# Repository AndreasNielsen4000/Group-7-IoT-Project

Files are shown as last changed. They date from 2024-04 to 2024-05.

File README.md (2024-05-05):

# Group 7 IoT Project: Wireless Stereo Speaker System
This one of the two github pages for Group 7s project for DTU course 34346 Networking technologies and application development for the Internet of Things (IoT).
## Group Members
- Andreas Nielsen: s203833
- Alexander Nordentoft: s176361
- Rasmus Kurdahl-Martinsen: s194337
- Sergio Piqueras Moreno: s232104
- Hugo Velasco Bombin: s233845
- Anton Per Rønnedal: s203821

## Project Description

The project is a wireless speaker system that can play music from a Bluetooth or WiFi source. The system consists of four main parts with subcomponents:

1. A speaker with an ESP32-WROOM-32 microcontroller.
   1. Two custom PCBs
      1. A power board with USB-C PD and a battery management system.
      2. An audio board with a class D amplifier, a DAC, ESP32-WROOM-32, and an nRF24L01 module.
      3. Rotary encoder for volume control and switching modes.
      4. OLED display for showing the current mode, metadata, battery level and volume.
2. ESP32 IoT Bridge
   1. An ESP32-WROOM-32 microcontroller.
   2. nRF24L01 module.
3. Azure Backend
    1. WebAPI for managing the speaker system.
    2. Simple front end for controlling the speaker system.
4. Thunkable App
    1. An app for controlling the speaker system using the Azure backend.

## Description of the Speaker System

*Code in BT_I2S_URL_OLED*

The speaker system consists of a speaker with an ESP32-WROOM-32 microcontroller. The speaker is powered by a custom power board with USB-C PD and a battery management system. The speaker can be powered by three 18650 batteries or by USB-C PD. The battery can be charged using USB-C PD.

The audio is played by a custom audio board with a class D amplifier.

The speaker can play music from a Bluetooth or WiFi source. The speaker can be controlled using the Thunkable app, the Azure backend or by using the rotary encoder and OLED display on the speaker.

When powering on the speaker, a byte will be read form the EEPROM to determine the mode of the speaker. The speaker can be in one of the following modes besides being powered off:
WiFi, Bluetooth, Standby or Charge

When powered on, a short press on the rotary encoder will switch betweent the current active mode to the valid passive mode, e.g. if the speaker is in WiFi mode and charging, a short press will switch to Charge mode. A short press again will switch back to WiFi mode. If the device is not charging, the speaker will go into Standby mode instead. From Standby mode, a long press (10 seconds) will turn off the speaker.

In all modes except powered off, the speaker will show the battery level on the OLED display as well as the current mode. It will have an active nRF network to the IoT Bridge and will be able to receive and transmit payloads from the nRF network.

Once a second the speaker checks for any changes in local device parameters and if they are different from the last time the speaker will send a payload to the IoT Bridge with the new parameters. Should the speaker receive a payload from the IoT Bridge, it will parse the payload and act accordingly.

When in WiFi mode, the speaker will start by playing Radio BOB! bby default. The speaker will show the current song and Internet Radio station on the OLED display.

When in Bluetooth mode, the speaker will connect to the last connected Bluetooth device and that device will be able to play music on the speaker. The speaker will show the current song on the OLED display. When connected to a compatible device, the speaker will show the current song on the OLED display and turning the volume down to 0 sends a pause command to the device. Turning the volume up will send a play command to the device.

When in Standby mode, the speaker will not play music, but the ESP32 will still be running with the OLED display and the nRF network active.

When in Charge mode, the speaker will charge the battery and show the battery level on the OLED display.

## Description of the IoT Bridge

*Code in NRF_COM_HUB*

The IoT Bridge consists of an ESP32-WROOM-32 microcontroller and an nRF24L01 module. The IoT Bridge is connected to the Azure backend using WiFi. The IoT Bridge sends a request to the Azure backend 5 second to check for any changes in the data. If the data has changed, the IoT Bridge sends the new data to the speaker system. The IoT Bridge receives data from the speaker system and sends it to the Azure backend.

## Description of the Azure Backend

*Code in https://github.com/AndreasNielsen4000/azureradioapi]https://github.com/AndreasNielsen4000/azureradioapi*

The Azure backend consists of a WebAPI for managing the speaker system. The WebAPI is connected to the IoT Bridge using WiFi. The WebAPI receives data from the IoT Bridge and sends data to the IoT Bridge. The WebAPI has a simple front end for controlling the speaker system.

## Description of the Thunkable App

*The block-code for the app can be found here https://x.thunkable.com/projectPage/65fbfc2f66a304c1d58aabaa*

Using Thunkable an app was created for controlling the speaker system using the Azure backend. The app can be used to change the mode of the speaker system, search for new Internet Radio stations, change Internet Radio station and change the volume.
The app works by using HTTP GET to search and filter Internet Radio URLs and then HTTP POST to the Azure with updated device parameters.

AppWelcomeScreen
AppSearchScreen

## Overview of Communication

ComFlow

## Video Preview of Functionality
In the following video, the device is powered on from the off-state, going into Bluetooth mode. The rotary encoder is turned up, issuing a play request to the connected iPhone. 
Then the device is switched over to WiFi mode and playing Radio BOB!.

https://github.com/AndreasNielsen4000/Group-7-IoT-Project/assets/8758884/1d90d405-0698-4473-90d2-c6516d68bdfd

## Work Distribution

| Responsibility | Main | Secondary |
|---|---|---|
| **Mobile App** | Andreas | Alexander |
| **OLED** | Alexander | ------ |
| **LEDs** | Sergio | ------ |
| **PCBs** | Anton | ------ |
| **Soldering** | Anton | ------ |
| **3D Design** | Sergio | Hugo |
| **Azure** | Rasmus | Andreas |
| **Back-end** | Andreas | Rasmus |
| **Front-end** | Andreas | Alexander |
| **IoT bridge** | Rasmus | Andreas, Alexander |
| **nRF** | Sergio | Rasmus, Andreas |
| **nRF Network** | Andreas | Alexander, Sergio |
| **WiFi (mode)** | Alexander | Andreas |
| **Bluetooth (mode)** | Alexander | Andreas |
| **EEPROM** | Alexander | ------ |
| **Battery Reading** | Rasmus | ------ |
| **Power Delivery** | Anton | ------ |
| **BMS** | Anton | ------ |
| **Rotary encoder** | Anton & Alexander | ------ |
| **State Machine** | Anton | ------ |
| **Code Integration** | Andreas & Alexander | Anton |
| **Final prototype assembly**  | Alexander, Anton & Sergio | ------ |
| **Report** | All | ------ |
| **Poster** | All | ------ |

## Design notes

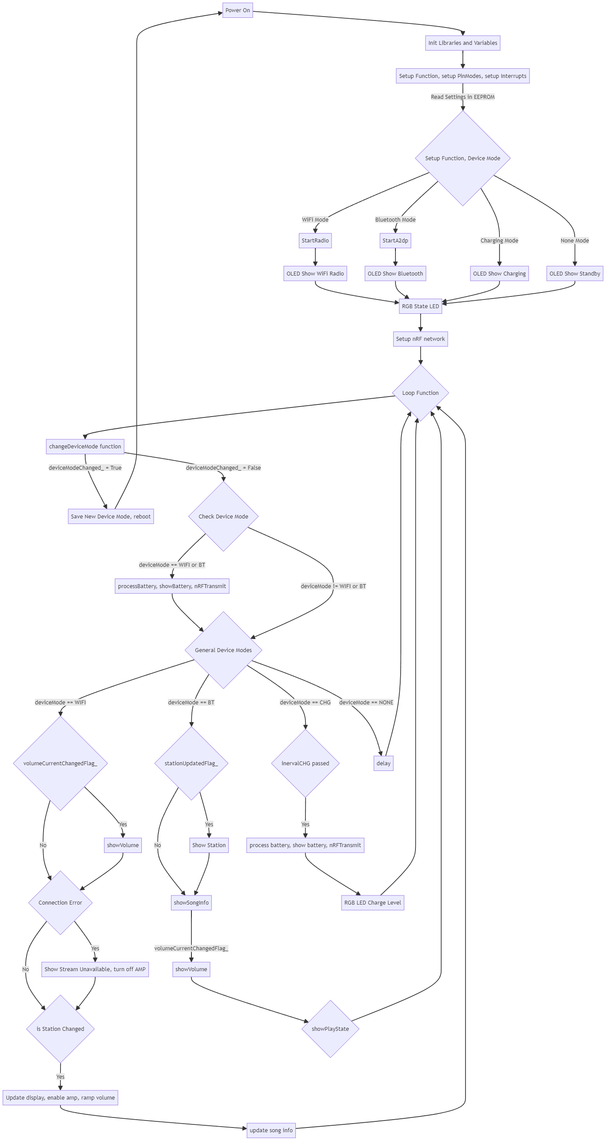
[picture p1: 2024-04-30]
speaker_code_overview.png

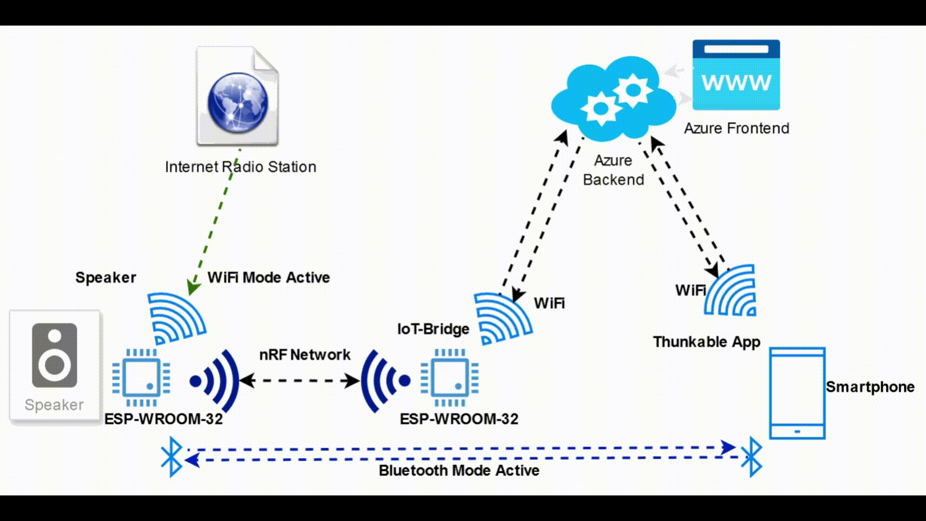
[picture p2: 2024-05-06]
ComFlow.gif

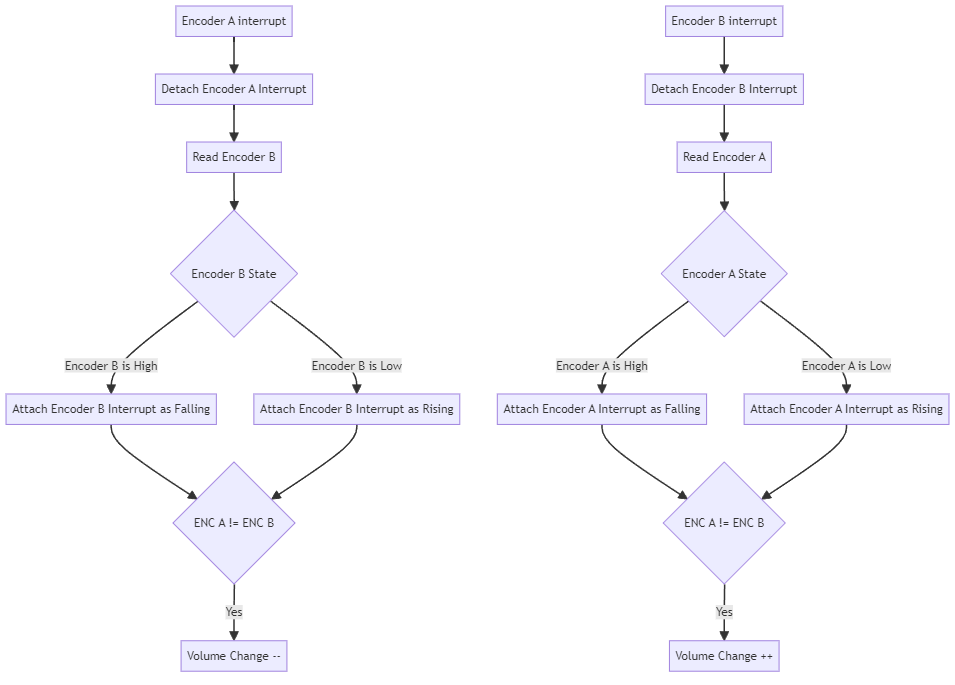
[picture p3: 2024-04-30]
Encoder flowchart.png

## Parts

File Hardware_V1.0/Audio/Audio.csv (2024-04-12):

Reference | Value | Footprint | Qty | MPN | Description
C29,C30 | 12p | Capacitor_SMD:C_0603_1608Metric_Pad1.08x0.95mm_HandSolder | 2 | CL10C120JB8NNNC | MLCC 50V 5% C0G
C28 | 100p | Capacitor_SMD:C_0603_1608Metric_Pad1.08x0.95mm_HandSolder | 1 | CL10C101JB8NNND | MLCC 50V 5% C0G
C14,C16,C27,C64,C65,C76 | 2.2n | Capacitor_SMD:C_0603_1608Metric_Pad1.08x0.95mm_HandSolder | 6 | CL10B222KB8NNND | MLCC 50V 10% X7R
C13 | 33n | Capacitor_SMD:C_0603_1608Metric_Pad1.08x0.95mm_HandSolder | 1 | CL10B333KB8NNNC | MLCC 50V 10% X7R
C1,C2,C4,C5,C6,C8,C9,C12,C15,C17,C21,C22,C49,C61,C62,C68,C69,C70,C71,C72,C73,C74,C75 | 100n | Capacitor_SMD:C_0603_1608Metric_Pad1.08x0.95mm_HandSolder | 23 | CL10B104JB8NNNC | MLCC 50V 5% X7R
C45,C46,C47,C48 | 220n | Capacitor_SMD:C_0603_1608Metric_Pad1.08x0.95mm_HandSolder | 4 | CL10B224KB8NNNC | MLCC 50V 5% X7R
C52,C53,C54,C55 | 470n | Capacitor_SMD:C_0805_2012Metric_Pad1.18x1.45mm_HandSolder | 4 | CL21B474KBFNNNE | MLCC 50V 10% X7R
C18,C19,C20,C23,C25,C26,C31 | 1u | Capacitor_SMD:C_0603_1608Metric_Pad1.08x0.95mm_HandSolder | 7 | CL10A105KB8NNNC | MLCC 50V 10% X5R
C10,C11 | 2.2u | Capacitor_SMD:C_0603_1608Metric_Pad1.08x0.95mm_HandSolder | 2 | CL10A225KP8NNNC | MLCC 10V 10% X5R
C7 | 4.7u | Capacitor_SMD:C_0603_1608Metric_Pad1.08x0.95mm_HandSolder | 1 | GRM188R6YA475KE15J | MLCC 35V 10% X5R
L1,L2,L3,L4,L5 | 10uH | 0_Costum:1274AS | 5 | DD1274AS-H-100M=P3 | Power inductor SMD 4.4A 20%
C3,C24,C32,C33,C34,C35,C36,C37,C38,C39,C40,C41,C42,C43,C44,C50,C51,C56,C57,C58,C59,C60,C63,C66,C67 | 10u | Capacitor_SMD:C_1206_3216Metric_Pad1.33x1.80mm_HandSolder | 25 | CL31B106KBHNNNE | MLCC 50V 10% X7R
Y1 | 16 MHz | Crystal:Crystal_SMD_2520-4Pin_2.5x2.0mm | 1 | ECS-160-10-36-CKM-TR3
R24,R25 | 470R | Resistor_SMD:R_0603_1608Metric_Pad0.98x0.95mm_HandSolder | 2 | CRCW0603470RFKEA | Thick Film Resistor 1/10watt 1%
R10,R21,R22,R26,R27,R31,R32 | 2k | Resistor_SMD:R_0603_1608Metric_Pad0.98x0.95mm_HandSolder | 7 | CRCW06032K00FKEC | Thick Film Resistor 1/10watt 1%
R4,R5 | 5.1k | Resistor_SMD:R_0603_1608Metric_Pad0.98x0.95mm_HandSolder | 2 | CRCW06035K10FKEA | Thick Film Resistor 1/10watt 1%
R34 | 5.6k | Resistor_SMD:R_0603_1608Metric_Pad0.98x0.95mm_HandSolder | 1 | CRCW06035K60FKEA | Thick Film Resistor 1/10watt 1%
R15,R16,R17,R19,R20 | 10k | Resistor_SMD:R_0603_1608Metric_Pad0.98x0.95mm_HandSolder | 5 | CRCW060310K0FKEC | Thick Film Resistor 1/10watt 1%
R8,R23,R29,R37 | 22k | Resistor_SMD:R_0603_1608Metric_Pad0.98x0.95mm_HandSolder | 4 | CRCW060322K0FKEA | Thick Film Resistor 1/10watt 1%
R9 | 47.5k | Resistor_SMD:R_0603_1608Metric_Pad0.98x0.95mm_HandSolder | 1 | CRCW060347K5FKEA | Thick Film Resistor 1/10watt 1%
R36 | 51k | Resistor_SMD:R_0603_1608Metric_Pad0.98x0.95mm_HandSolder | 1 | CRCW060351K0FKEA | Thick Film Resistor 1/10watt 1%
R3,R12,R13,R14,R35 | 100k | Resistor_SMD:R_0603_1608Metric_Pad0.98x0.95mm_HandSolder | 5 | CRCW0603100KFKEA | Thick Film Resistor 1/10watt 1%
R7 | 200k | Resistor_SMD:R_0603_1608Metric_Pad0.98x0.95mm_HandSolder | 1 | CRCW0603200KFKEA | Thick Film Resistor 1/10watt 1%
R1,R2,R6,R11,R30,R38 | 1M | Resistor_SMD:R_0603_1608Metric_Pad0.98x0.95mm_HandSolder | 6 | CRCW06031M00FKEC | Thick Film Resistor 1/10watt 1%
R28,R33,R39,R40 | (NC) | Resistor_SMD:R_0603_1608Metric_Pad0.98x0.95mm_HandSolder | 4
D10,D11,D12 | 1N4148W | Diode_SMD:D_SOD-123 | 3
U5 | 2450BM14E0002T | Snapeda:2450BM14E0003T_JOT-L | 1 | 2450BM14A0002T
Q1,Q2 | BC817 | Package_TO_SOT_SMD:SOT-23 | 2 | BC817-QR | NPN transistor, base/emitter/collector
SW2 | BOOT | Button_Switch_SMD:Panasonic_EVQPUK_EVQPUB | 1 | EVQ-PUK02K | Tactile Switch
J2,J3,J4,J5 | Conn_01x04 | Connector_PinSocket_2.54mm:PinSocket_1x04_P2.54mm_Vertical | 4 |  | Generic connector, single row, 01x04, script generated (kicad-library-utils/schlib/autogen/connector/)
U2 | CP2102N-Axx-xQFN28 | Package_DFN_QFN:QFN-28-1EP_5x5mm_P0.5mm_EP3.35x3.35mm | 1 | CP2102N-A02-GQFN28 | USB to UART master bridge, QFN-28
SW3 | EN | Button_Switch_SMD:Panasonic_EVQPUK_EVQPUB | 1 | EVQ-PUK02K | Tactile Switch
U1 | ESP32-WROOM-32E | RF_Module:ESP32-WROOM-32D | 1 | ESP32-WROOM-32E-N16 | RF Module, ESP32-D0WD-V3 SoC, without PSRAM, Wi-Fi 802.11b/g/n, Bluetooth, BLE, 32-bit, 2.7-3.6V, onboard antenna, SMD
H1,H2,H3,H4 | Hole | MountingHole:MountingHole_3.2mm_M3_DIN965_Pad | 4 |  | Mounting Hole with connection
JP1 | Jumper | Jumper:SolderJumper-3_P1.3mm_Bridged12_RoundedPad1.0x1.5mm | 1 |  | 3-pole Solder Jumper, pins 1+2 closed/bridged
D9 | LED_amber | LED_SMD:LED_0603_1608Metric_Pad1.05x0.95mm_HandSolder | 1 | 150060YS75000
D8,D13 | LED_green | LED_SMD:LED_0603_1608Metric_Pad1.05x0.95mm_HandSolder | 2 | 150060GS75000
D14 | LED_red | LED_SMD:LED_0603_1608Metric_Pad1.05x0.95mm_HandSolder | 1 | 150060RS75000
U7 | LMR51430 | Package_TO_SOT_SMD:SOT-23-6 | 1 | LMR51430YDDCR | 4.5-V to 36-V, 3-A synchronous buck converter with 40-µA IQ, SOT-23-6
AE1 | MIFA | RF_Antenna:Texas_SWRA117D_2.4GHz_Right | 1 |  | Antenna with extra pin for shielding
U4 | nRF24L01P | Package_DFN_QFN:QFN-20-1EP_4x4mm_P0.5mm_EP2.5x2.5mm | 1 | nRF24L01P | nRF24L01+, Ultra low power 2.4GHz RF Transceiver, QFN20 4x4mm
U3 | PCM5101A | Package_SO:TSSOP-20_4.4x6.5mm_P0.65mm | 1 | PCM5101AQPWRQ1 | 2.1 VRMS, 106dB Audio Stereo DAC with PLL and 32-bit, 384kHz PCM Interface, TSSOP-20
D1,D2,D3,D5,D6 | PMEG60T | Diode_SMD:Nexperia_CFP3_SOD-123W | 5 | PMEG60T30ELRX
D4,D15 | PMEG3020ER | Diode_SMD:Nexperia_CFP3_SOD-123W | 2 | PMEG3020ER,115
D7 | RGB LED | 0_Costum:RGB_LED | 1
SW1 | Rotary Encoder | 0_Costum:EC11_RotaryEncoder | 1
SW4 | SW_DIP_x02 | Button_Switch_SMD:SW_DIP_SPSTx02_Slide_6.7x6.64mm_W8.61mm_P2.54mm_LowProfile | 1 | 219-2MST | 2x DIP Switch, Single Pole Single Throw (SPST) switch, small symbol
J6,J7 | Terminal | TerminalBlock:TerminalBlock_bornier-2_P5.08mm | 2 |  | Generic screw terminal, single row, 01x02, script generated (kicad-library-utils/schlib/autogen/connector/)
U6 | TPA3128 | 0_Costum:DAP32_4P36X4P11_TEX | 1 | TPA3128D2DAPR
J1 | USB_C_Receptacle | Connector_USB:USB_C_Receptacle_GCT_USB4105-xx-A_16P_TopMnt_Horizontal | 1 | USB4105-GF-A-120 | USB 2.0-only 16P Type-C Receptacle connector

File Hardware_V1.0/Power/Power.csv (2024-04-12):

Reference | Value | Footprint | Qty | MPN | Description
B3 | ~ | 0_Costum:BLM_18650x3 | 1
C1,C2,C3,C4,C5,C8,C9,C10,C16,C17,C18,C25,C27,C28,C29,C30 | 100n | Capacitor_SMD:C_0603_1608Metric_Pad1.08x0.95mm_HandSolder | 16 | CL10B104JB8NNNC | MLCC 50V 5% X7R
C6,C7,C12,C13,C14,C15,C22,C24,C26,C35 | 1u | Capacitor_SMD:C_0603_1608Metric_Pad1.08x0.95mm_HandSolder | 10 | CL10A105KB8NNNC | MLCC 50V 10% X5R
C11 | 4.7u | Capacitor_SMD:C_0603_1608Metric_Pad1.08x0.95mm_HandSolder | 1 | GRM188R6YA475KE15J | MLCC 35V 10% X5R
C19,C20,C21,C31,C33,C34 | 10u | Capacitor_SMD:C_1206_3216Metric_Pad1.33x1.80mm_HandSolder | 6 | CL31B106KBHNNNE | MLCC 50V 10% X7R
C23 | 33n | Capacitor_SMD:C_0603_1608Metric_Pad1.08x0.95mm_HandSolder | 1 | CL10B333KB8NNNC | MLCC 50V 10% X7R
C32 | 22p | Capacitor_SMD:C_0603_1608Metric_Pad1.08x0.95mm_HandSolder | 1 | CL10C220JB8NNNC | MLCC 50V 5% C0G
D1,D8 | PMEG60T | Diode_SMD:Nexperia_CFP3_SOD-123W | 2 | PMEG60T30ELRX
D2,D3,D4 | ESDA25P35 | Snapeda:QFN1610_STM-L | 3 | ESDA25P35-1U1M
D5,D7 | LED_green | LED_SMD:LED_0603_1608Metric_Pad1.05x0.95mm_HandSolder | 2 | 150060GS75000
D6 | LED_amber | LED_SMD:LED_0603_1608Metric_Pad1.05x0.95mm_HandSolder | 1 | 150060YS75000
D9,D10 | PMEG3020ER | Diode_SMD:Nexperia_CFP3_SOD-123W | 2 | PMEG3020ER,115
D11 | ESDA25W | Package_TO_SOT_SMD:SOT-323_SC-70_Handsoldering | 1 | ESDA25W | TVS Diode Array
H1,H2,H3,H4 | Hole | MountingHole:MountingHole_3.2mm_M3_DIN965_Pad | 4 |  | Mounting Hole with connection
J1,J8,J9,J10,J11 | Conn_01x04 | -- mixed values -- | 5 | -- mixed values -- | -- mixed values --
J2 | (NC) | Connector_BarrelJack:BarrelJack_Wuerth_694106106102_2.0x5.5mm | 1 | 694106106102 | DC Barrel Jack with an internal switch
J5 | Barrel_Jack_Switch | Connector_BarrelJack:BarrelJack_Wuerth_694106106102_2.0x5.5mm | 1 | 694106106102 | DC Barrel Jack with an internal switch
J6 | USB_C_Receptacle_USB2.0_16P | Connector_USB:USB_C_Receptacle_GCT_USB4105-xx-A_16P_TopMnt_Horizontal | 1 | USB4105-GF-A-120 | USB 2.0-only 16P Type-C Receptacle connector
L1 | 10uH | 0_Costum:1274AS | 1 | DD1274AS-H-100M=P3 | Power inductor SMD 4.4A 20%
Q1,Q3,Q9,Q10 | SiRA88DP | Package_SO:PowerPAK_SO-8_Single | 4 | SIRA88DP-T1-GE3
Q2,Q4 | Si2369DS | Package_TO_SOT_SMD:SOT-23 | 2 | SI2369DS-T1-GE3
Q6,Q7,Q8,Q11 | SiS413DN | Package_SO:Vishay_PowerPAK_1212-8_Single | 4 | SIS413DN-T1-GE3
R1,R22,R23,R40 | 5.1k | Resistor_SMD:R_0603_1608Metric_Pad0.98x0.95mm_HandSolder | 4 | CRCW06035K10FKEA | Thick Film Resistor 1/10watt 1%
R2,R3,R4,R5,R8,R10,R30,R44 | 100R | Resistor_SMD:R_0603_1608Metric_Pad0.98x0.95mm_HandSolder | 8 | CRCW0603100RFKEC | Thick Film Resistor 1/10watt 1%
R6,R20,R25,R37,R48 | 1k | Resistor_SMD:R_0603_1608Metric_Pad0.98x0.95mm_HandSolder | 5 | CRCW06031K00FKEC | Thick Film Resistor 1/10watt 1%
R7,R12,R13,R15,R21,R35,R42 | 10k | Resistor_SMD:R_0603_1608Metric_Pad0.98x0.95mm_HandSolder | 7 | CRCW060310K0FKEC | Thick Film Resistor 1/10watt 1%
R11,R17,R18,R49 | 1M | Resistor_SMD:R_0603_1608Metric_Pad0.98x0.95mm_HandSolder | 4 | CRCW06031M00FKEC | Thick Film Resistor 1/10watt 1%
R14 | 750k | Resistor_SMD:R_0603_1608Metric_Pad0.98x0.95mm_HandSolder | 1 | CRCW0603750KFKEA | Thick Film Resistor 1/10watt 1%
R16,R46 | 430k | Resistor_SMD:R_0603_1608Metric_Pad0.98x0.95mm_HandSolder | 2 | CRCW0603430KFKEA | Thick Film Resistor 1/10watt 1%
R19 | 8m | 0_Costum:SenseResistor_1206 | 1 | MSMA1206R0080FCM | Current sense resistor 1W 1% 50 PPM/C
R24 | 470R | Resistor_SMD:R_0603_1608Metric_Pad0.98x0.95mm_HandSolder | 1 | CRCW0603470RFKEC | Thick Film Resistor 1/10watt 1%
R28,R34,R36,R39,R41 | 100k | Resistor_SMD:R_0603_1608Metric_Pad0.98x0.95mm_HandSolder | 5 | CRCW0603100KFKEA | Thick Film Resistor 1/10watt 1%
R29 | 22k | Resistor_SMD:R_0603_1608Metric_Pad0.98x0.95mm_HandSolder | 1 | CRCW060322K0FKEA | Thick Film Resistor 1/10watt 1%
R38 | 10R | Resistor_SMD:R_0603_1608Metric_Pad0.98x0.95mm_HandSolder | 1 | CRCW060310R0FKEC | Thick Film Resistor 1/10watt 1%
R43,R47 | 10m | 0_Costum:SenseResistor_1206 | 2 | MFSA1206R0100FCM | Current sense resistor 1W 1% 50 PPM/C
R45 | 9.1k | Resistor_SMD:R_0603_1608Metric_Pad0.98x0.95mm_HandSolder | 1 | CRCW06039K10FKEA | Thick Film Resistor 1/10watt 1%
R50 | 200k | Resistor_SMD:R_0603_1608Metric_Pad0.98x0.95mm_HandSolder | 1 | CRCW0603200KFKEA | Thick Film Resistor 1/10watt 1%
TH1,TH3 | NCP18XH103 | Resistor_SMD:R_0603_1608Metric_Pad0.98x0.95mm_HandSolder | 2 | NCP18XH103F03RB
U1 | TAS:BQ7791500 | Package_SO:TSSOP-24_4.4x7.8mm_P0.65mm | 1 | BQ7791500PWR
U2 | STUSB4500 | Package_DFN_QFN:QFN-24-1EP_4x4mm_P0.5mm_EP2.7x2.7mm | 1 | STUSB4500QTR
U3 | BQ24617 | Package_DFN_QFN:QFN-24-1EP_4x4mm_P0.5mm_EP2.15x2.15mm_ThermalVias | 1 | BQ24617RGER

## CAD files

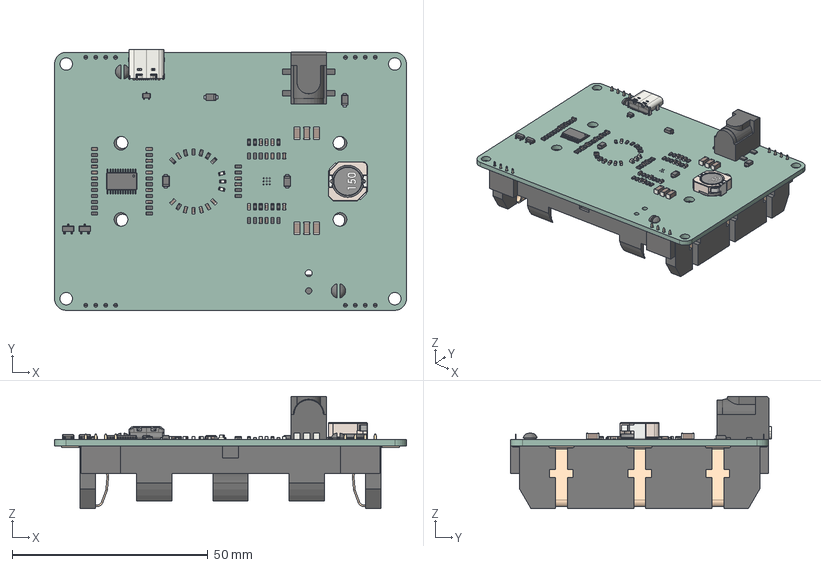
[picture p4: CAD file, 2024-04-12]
Hardware_V1.0/Power/Power.step
90.0 x 66.7 x 28.7 mm
R_0603_1608Metric x 43
C_1206_3216Metric x 6
C_0603_1608Metric x 29
CQ assembly x 4
USB_C_Receptacle_16P_TopMnt_Horizontal_GCT_USB4105-xx-A
WURTH_7447713150
LED_0603_1608Metric x 3
SOT_323_SC_70
SOT_23 x 2
TSSOP_24_44x78mm_P065mm
BarrelJackSMD v3
Hold_18650-3p_smd
PinSocket_1x04_P254mm_Vertical x 4
_autosave-Power_PCB

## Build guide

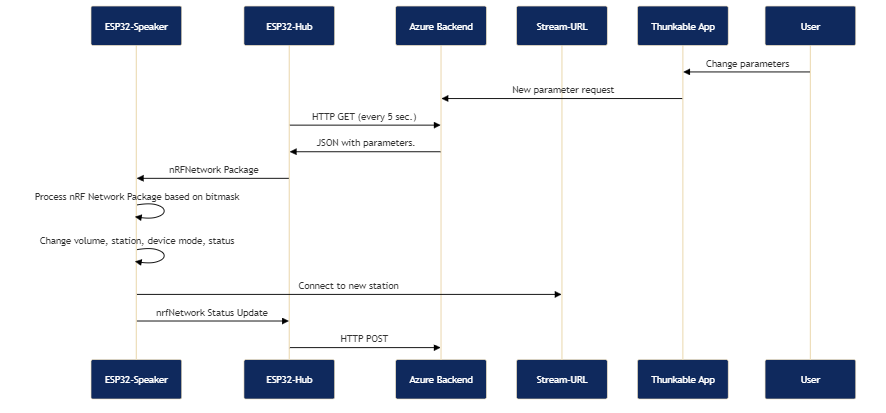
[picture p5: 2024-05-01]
User operation flow chart.png

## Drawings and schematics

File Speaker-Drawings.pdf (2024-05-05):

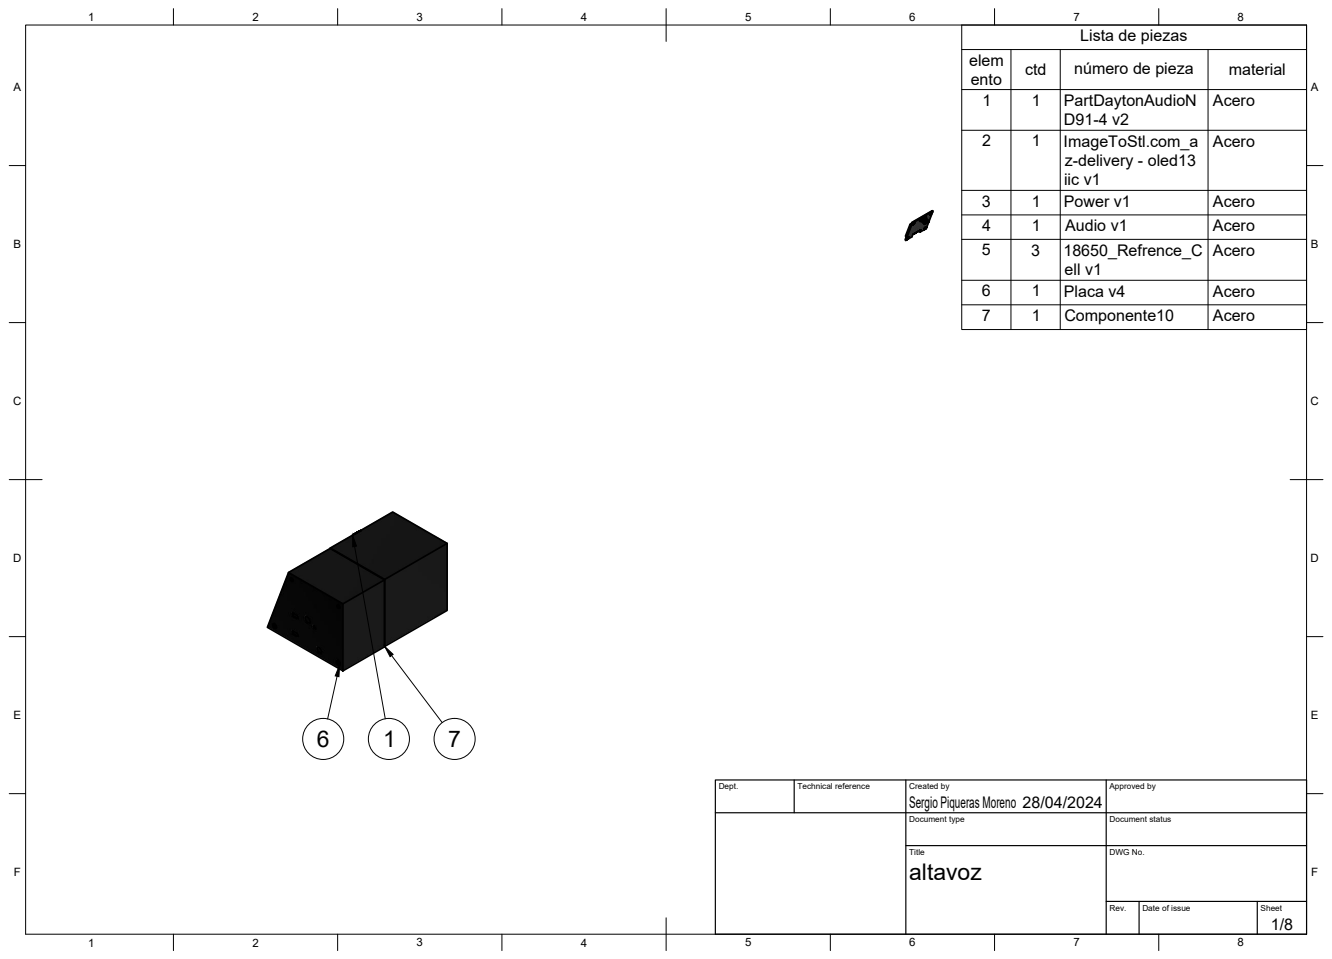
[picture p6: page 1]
Title; DWG No.; Rev.; Date of issue; Sheet

Lista de piezas

elem ento | ctd | número de pieza | material

1 | 1 | PartDaytonAudioN D91-4 v2 | Acero

2 | 1 | ImageToStl.com_a z-delivery - oled13 iic v1 | Acero

3 | 1 | Power v1 | Acero
4 | 1 | Audio v1 | Acero
5 | 3 | 18650_Refrence_C ell v1 | Acero

6 | 1 | Placa v4 | Acero
7 | 1 | Componente10 | Acero

Dept. | Technical reference | Created by Sergio Piqueras Moreno 28/04/2024 | Approved by

Document type | Document status

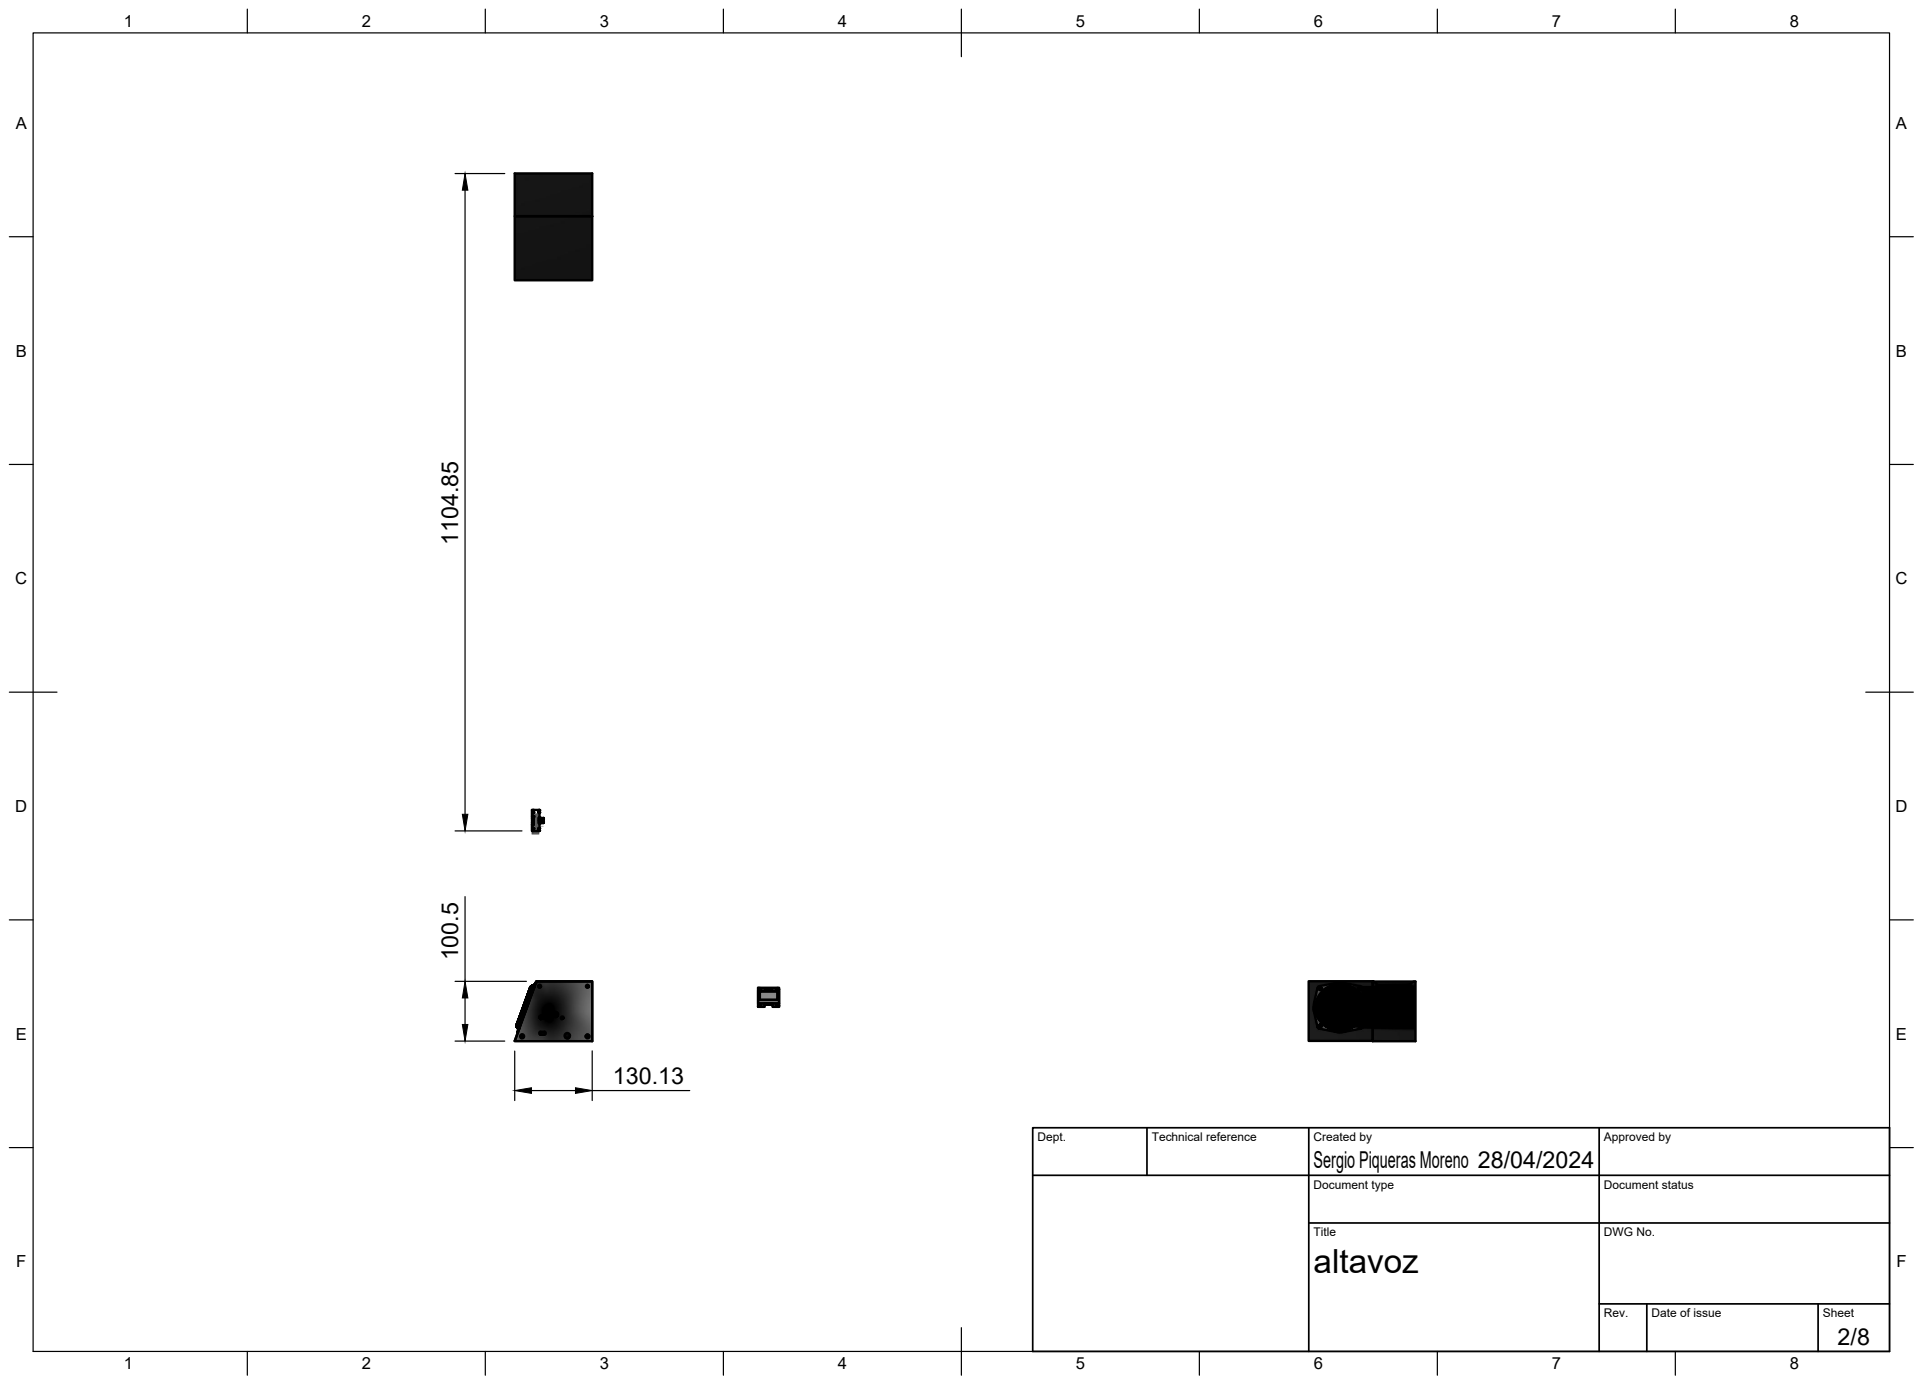
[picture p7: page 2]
Dept.; Technical reference; Created by; Approved by; Document type; Document status; Title; DWG No.

Sergio Piqueras Moreno

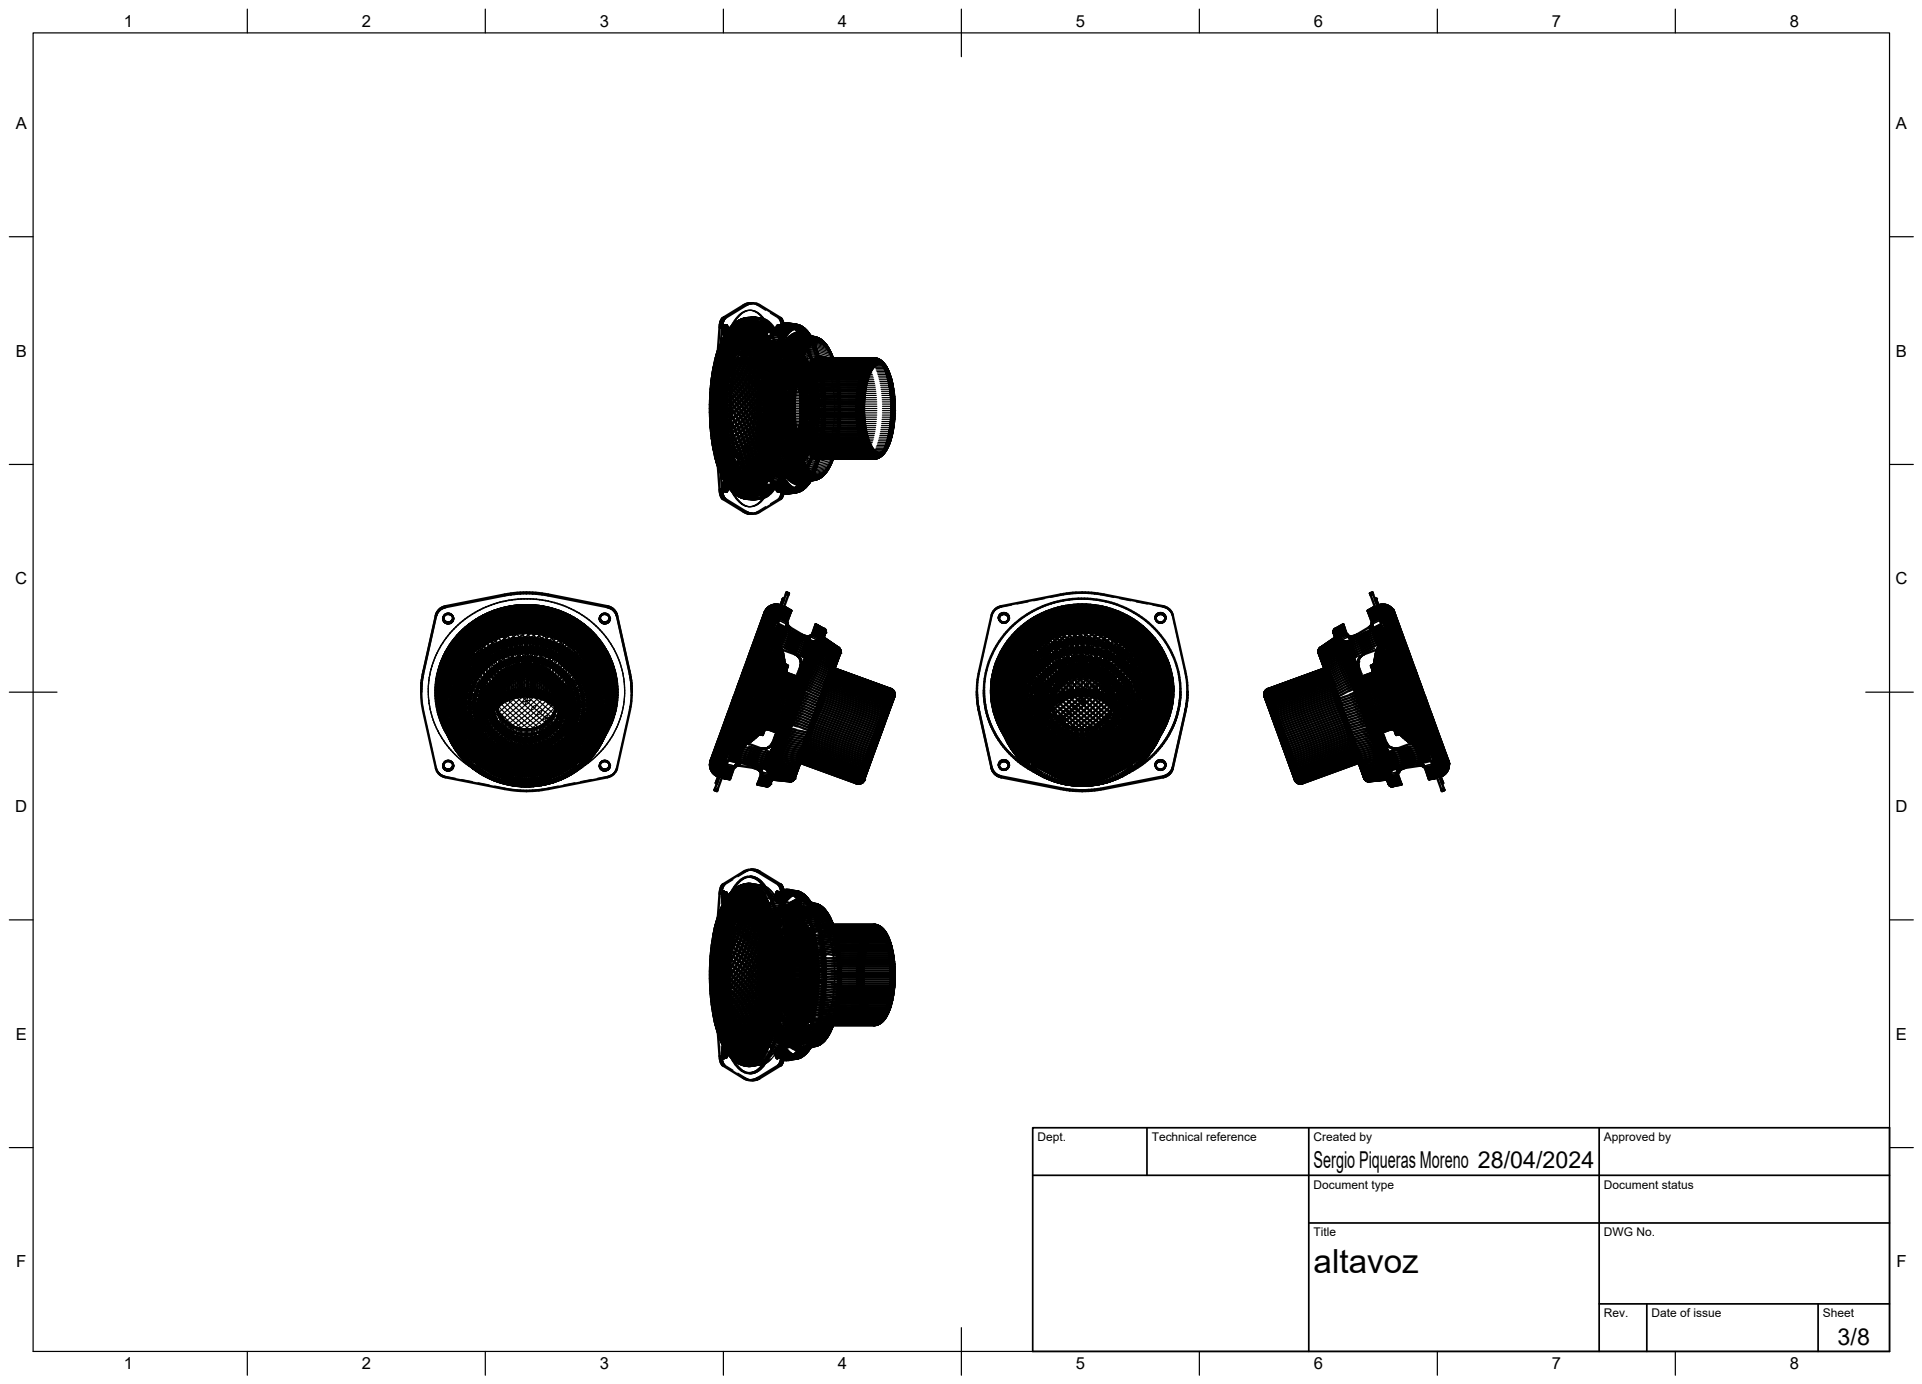
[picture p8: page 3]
Dept.; Technical reference; Created by; Approved by; Document type; Document status; Title; DWG No.

Sergio Piqueras Moreno

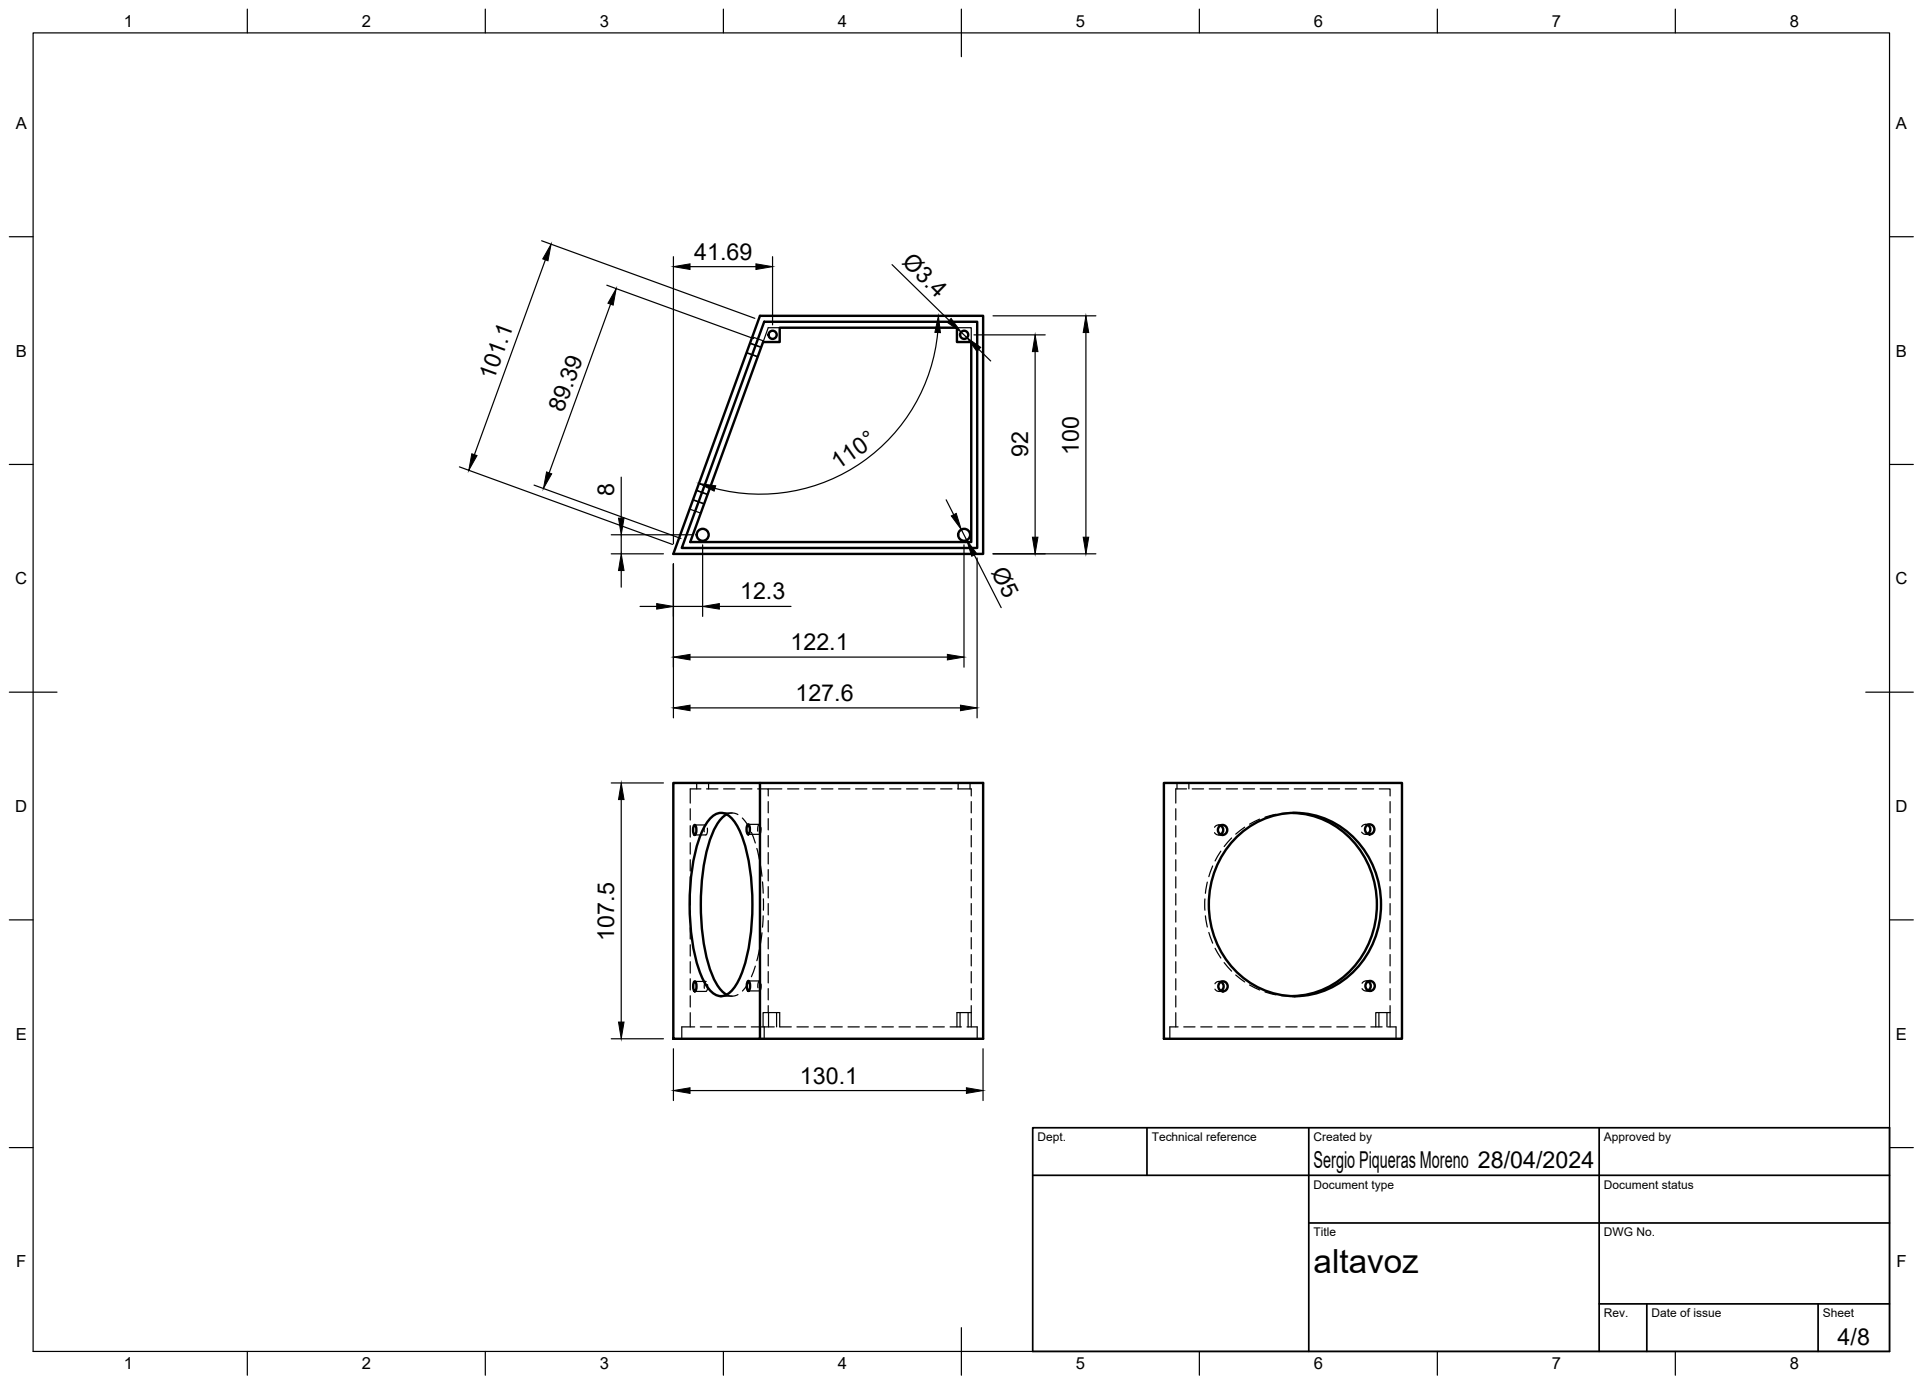
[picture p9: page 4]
Title; DWG No.

Sergio Piqueras Moreno 107.5

Dept. | Technical reference | Created by 28/04/2024 | Approved by

Document type | Document status

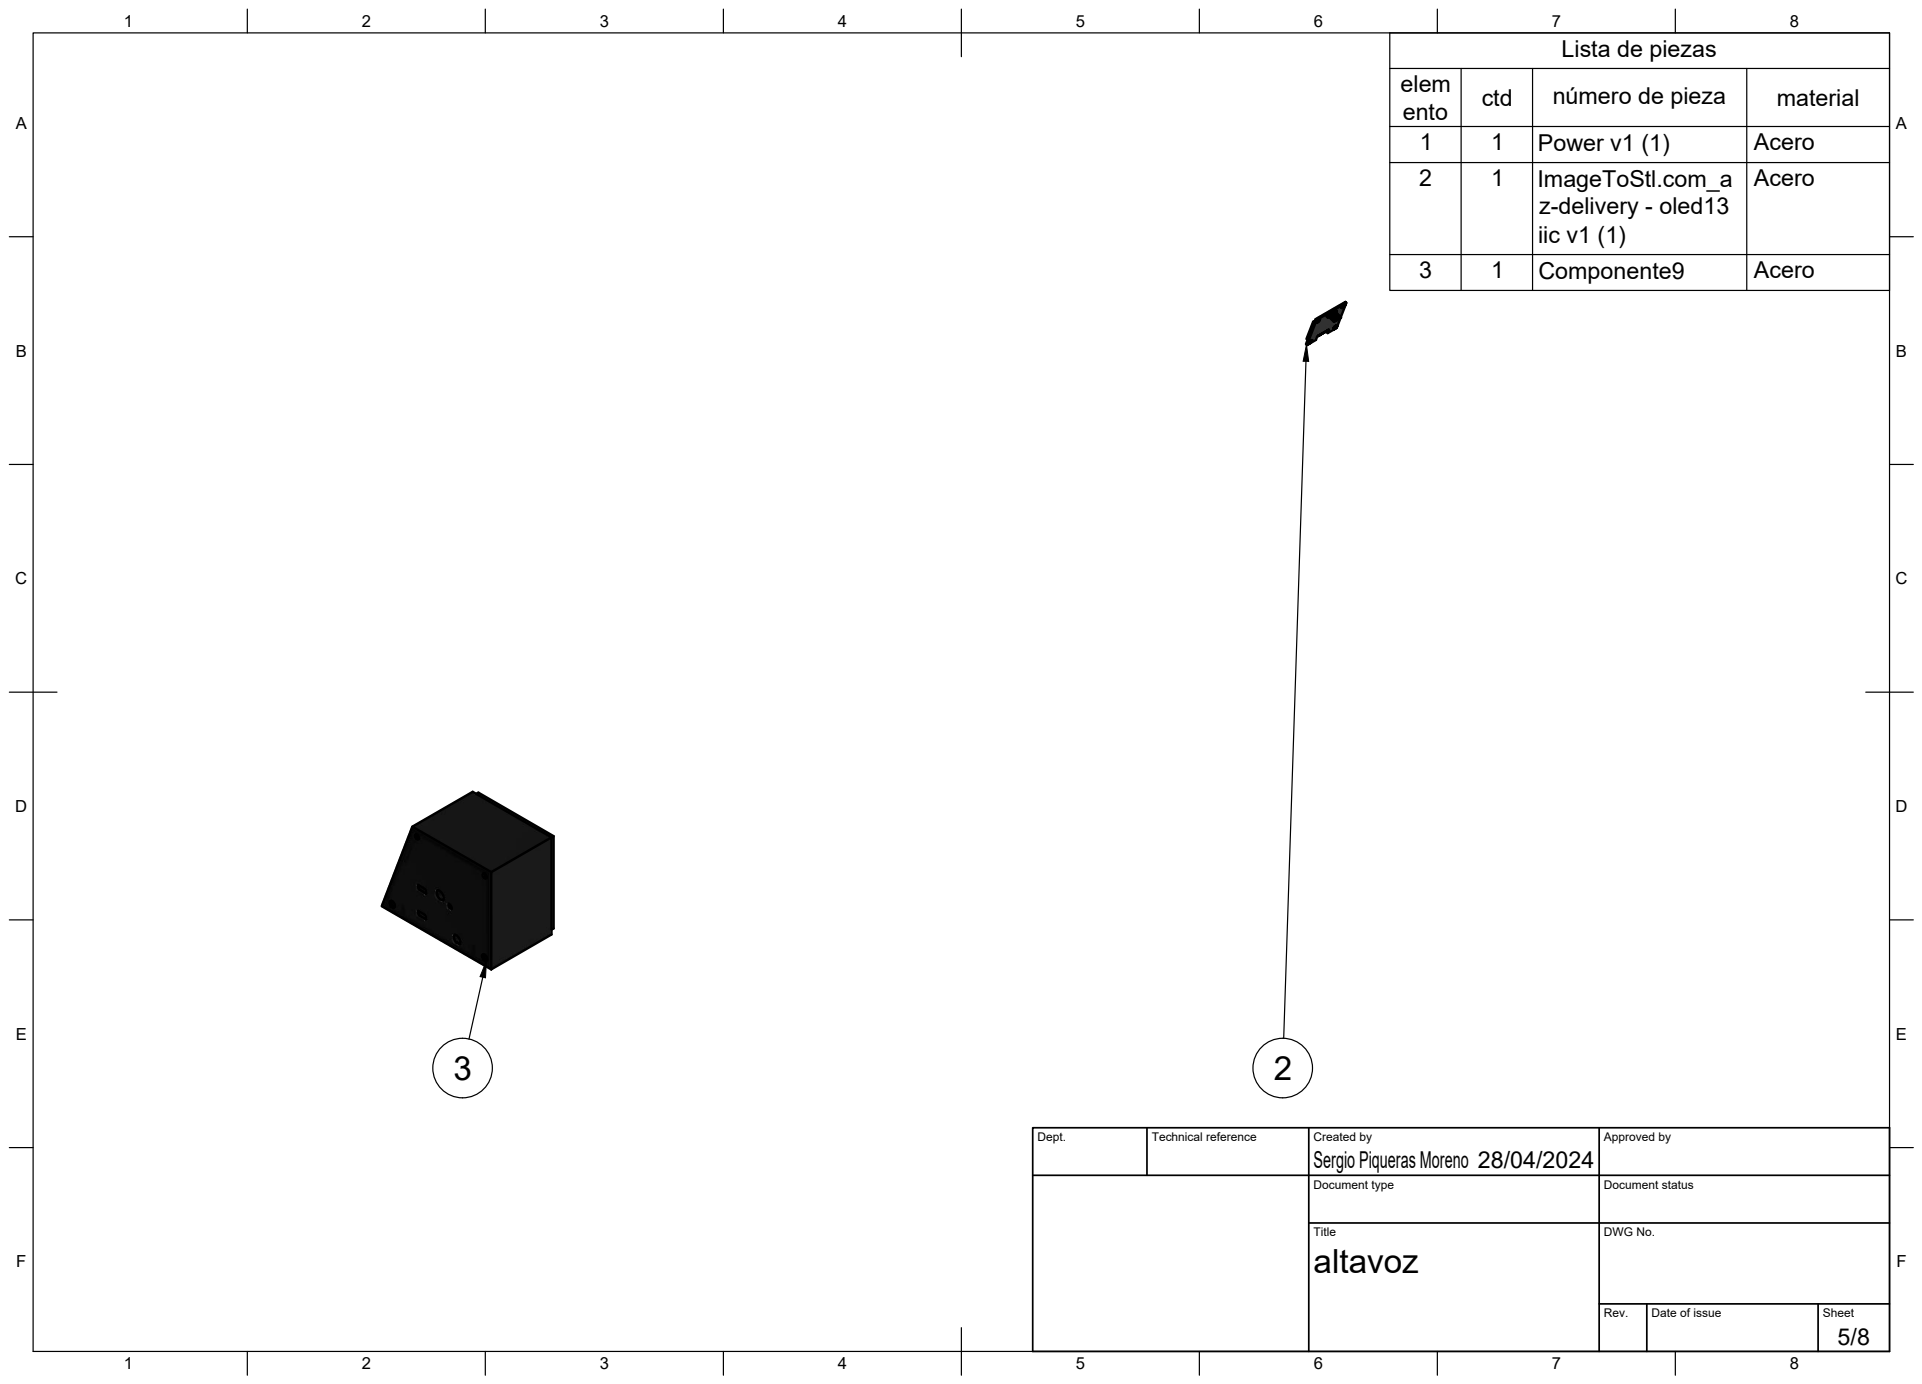
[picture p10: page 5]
Title; DWG No.

Lista de piezas

elem ento | ctd | número de pieza | material

1 | 1 | Power v1 (1) | Acero
2 | 1 | ImageToStl.com_a z-delivery - oled13 iic v1 (1) | Acero

3 | 1 | Componente9 | Acero

Dept. | Technical reference | Created by Sergio Piqueras Moreno 28/04/2024 | Approved by

Document type | Document status

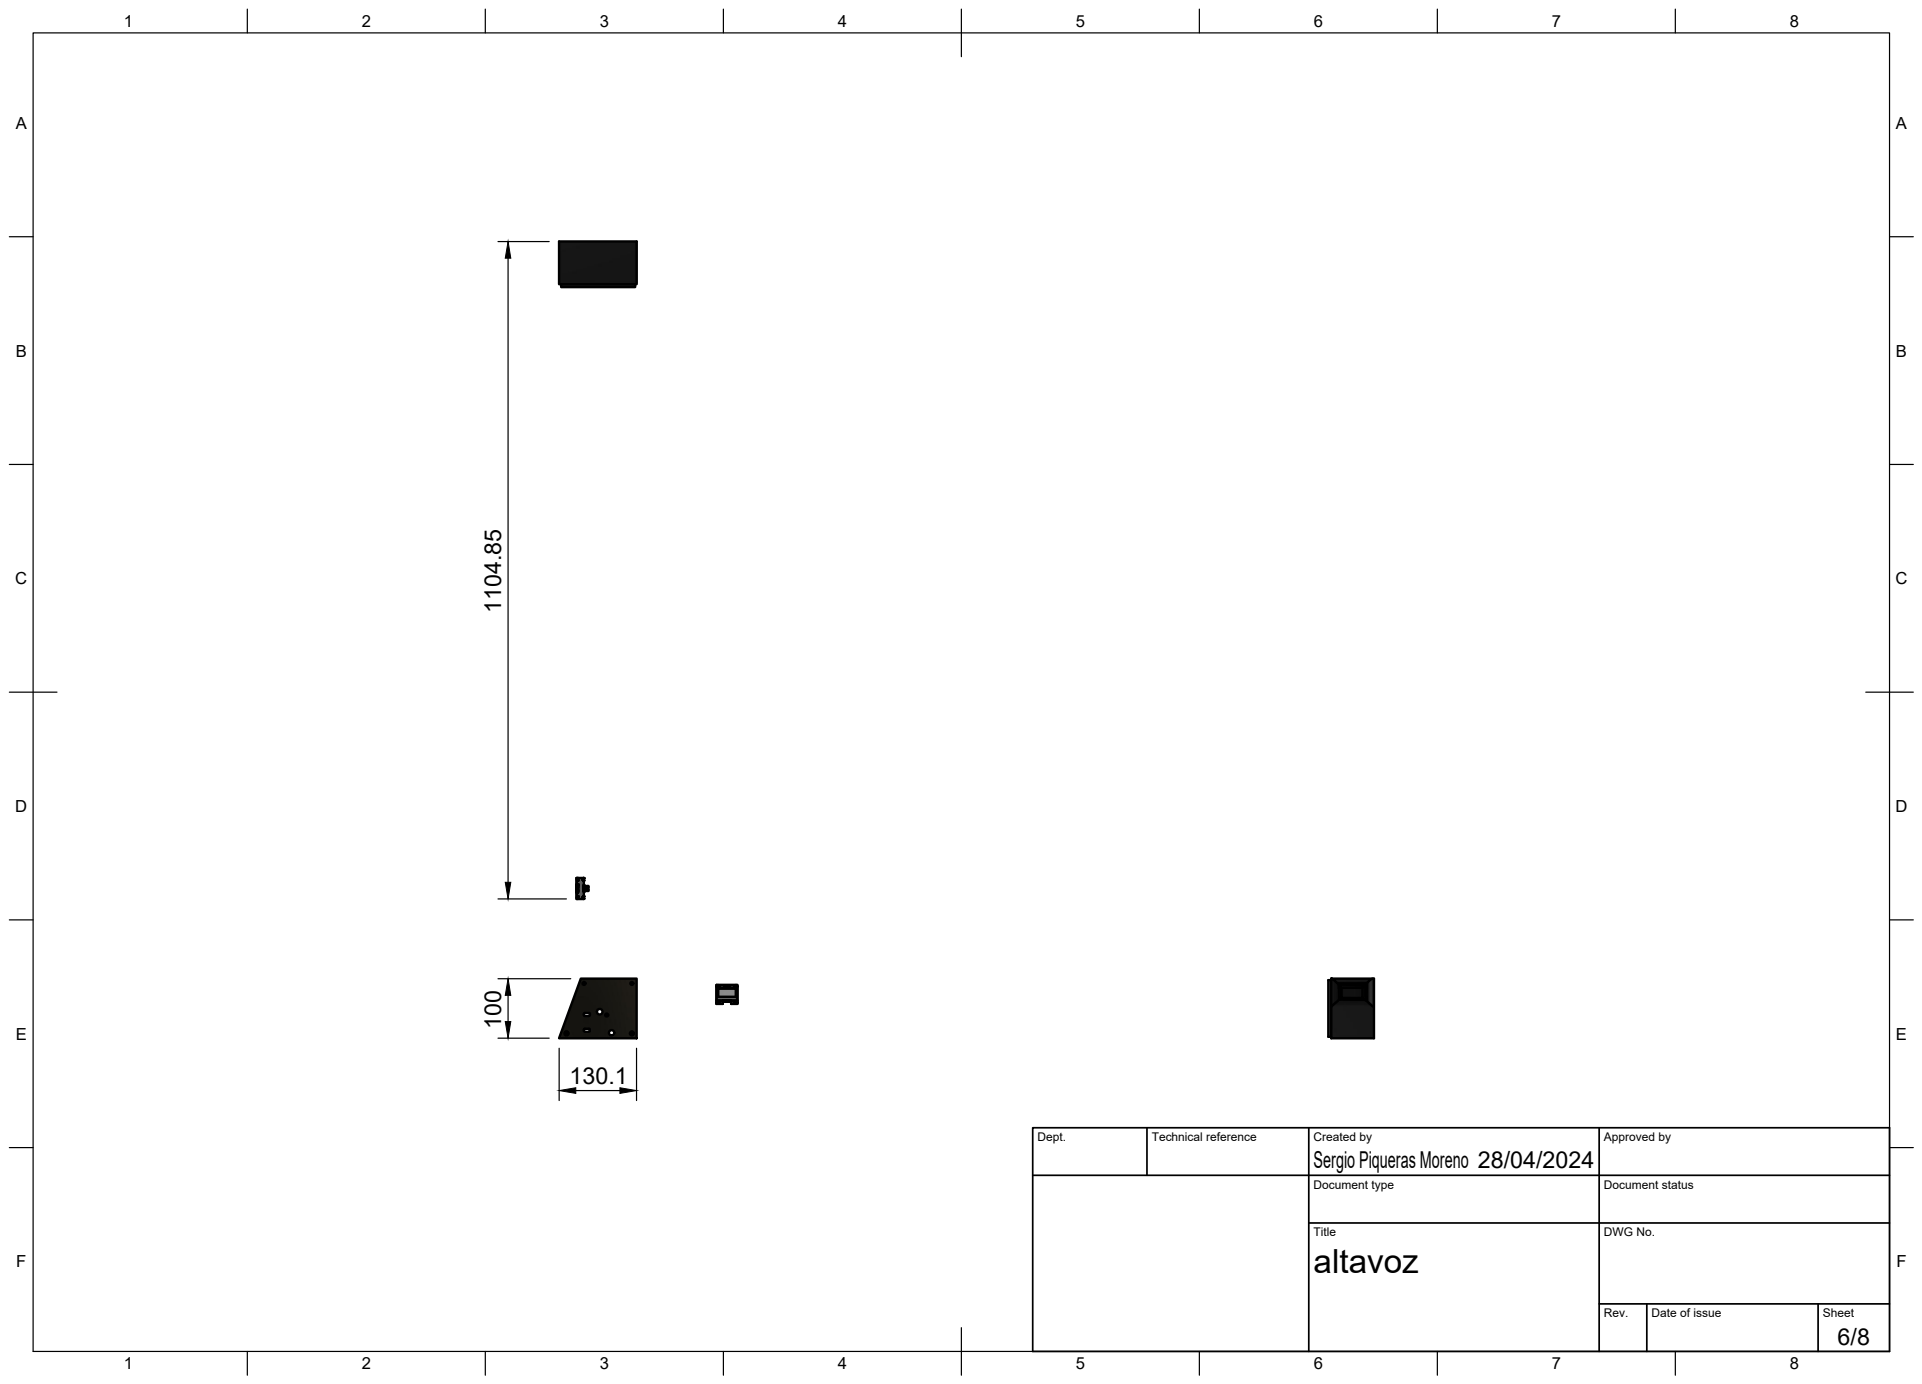
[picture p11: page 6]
Title; DWG No.

Dept. | Technical reference | Created by Sergio Piqueras Moreno 28/04/2024 | Approved by

Document type | Document status

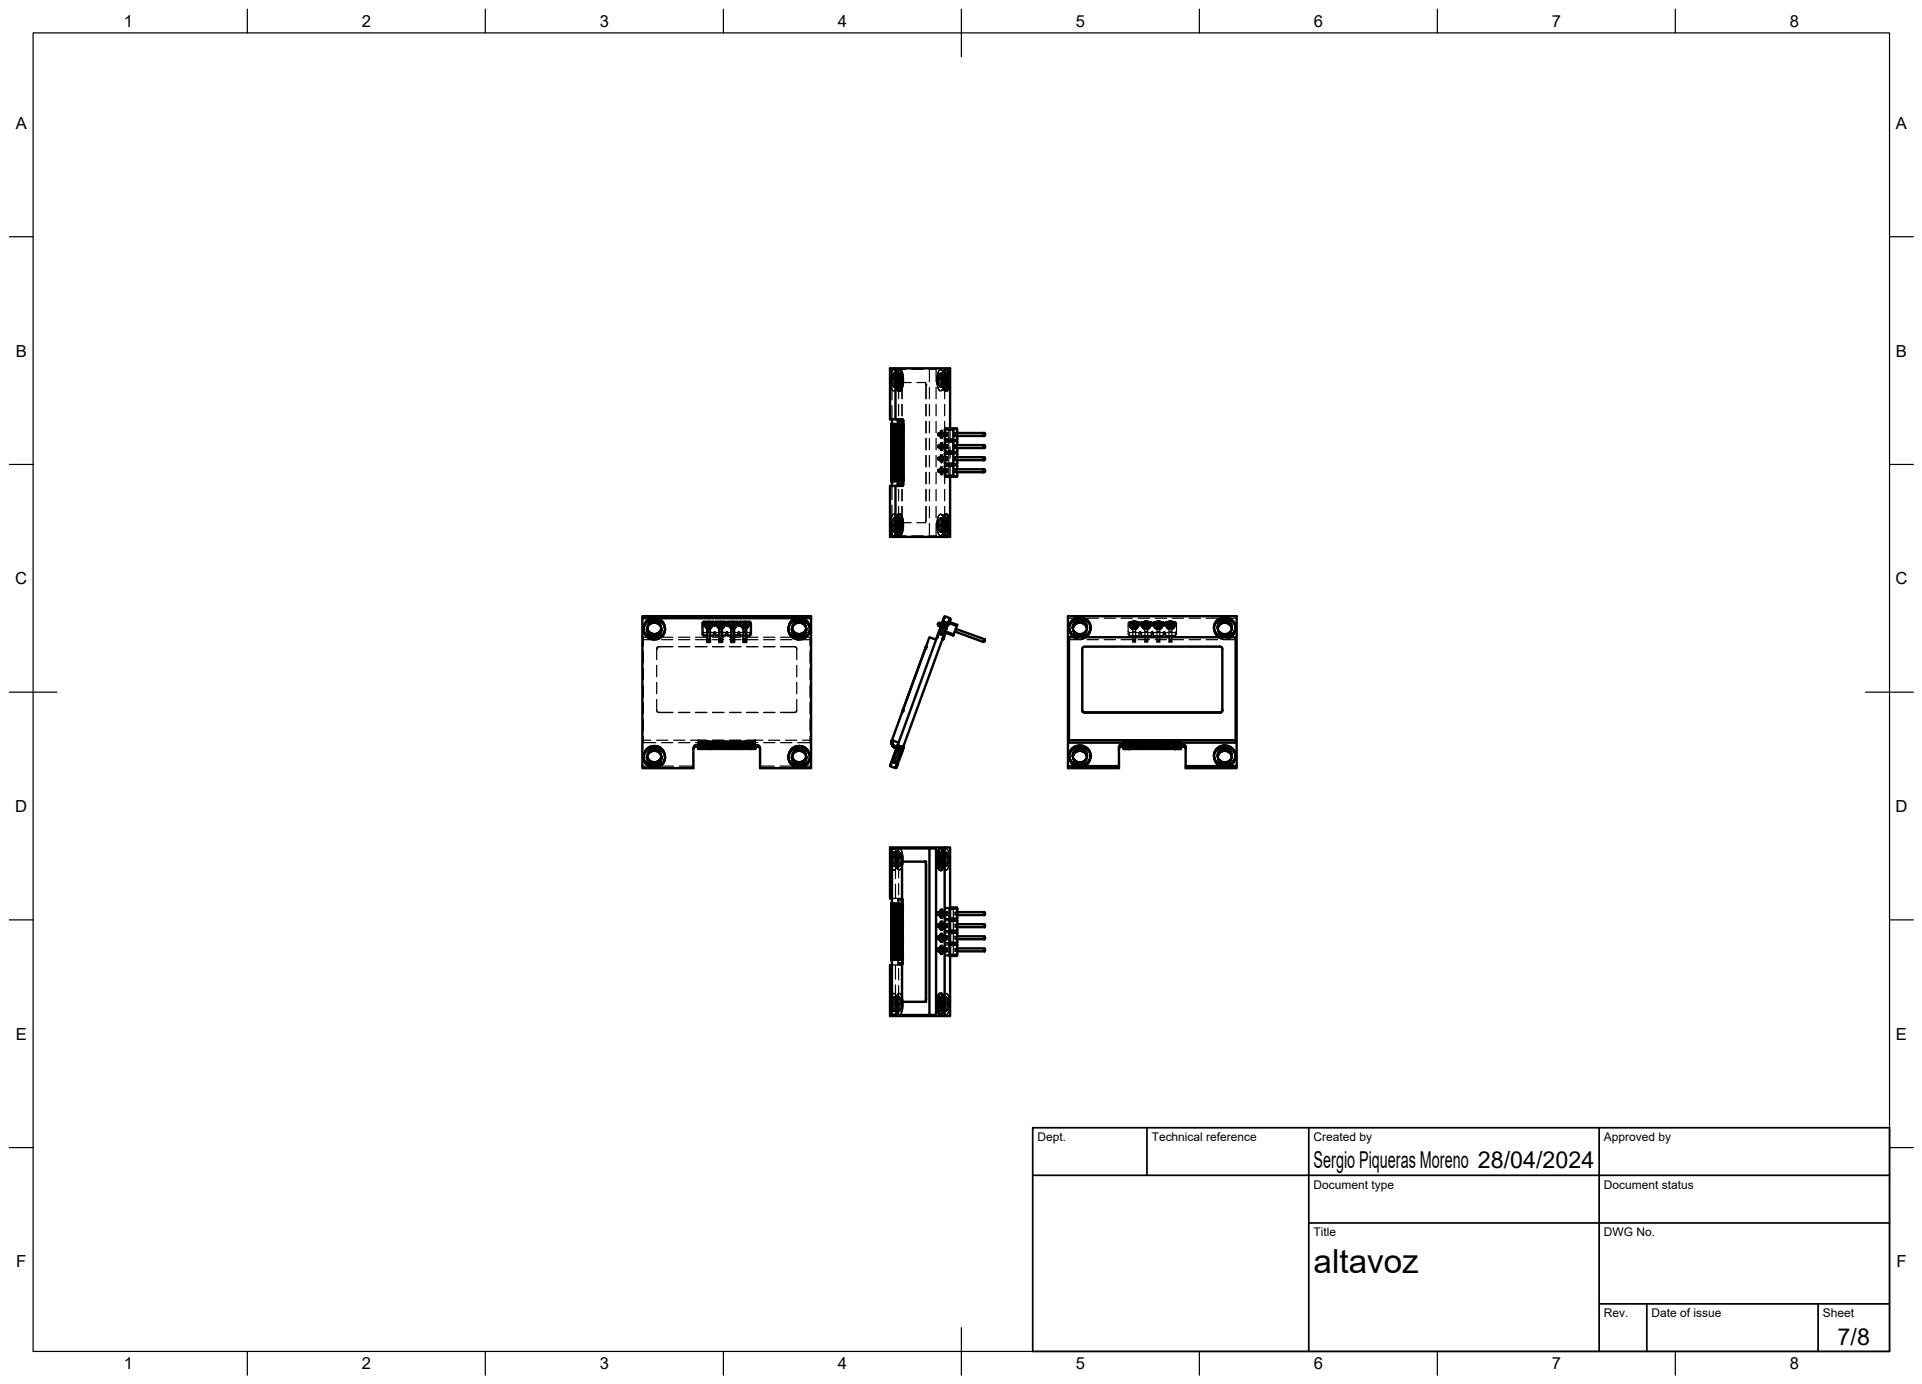
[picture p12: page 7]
Dept.; Technical reference; Created by; Approved by; Document type; Document status; Title; DWG No.

Sergio Piqueras Moreno

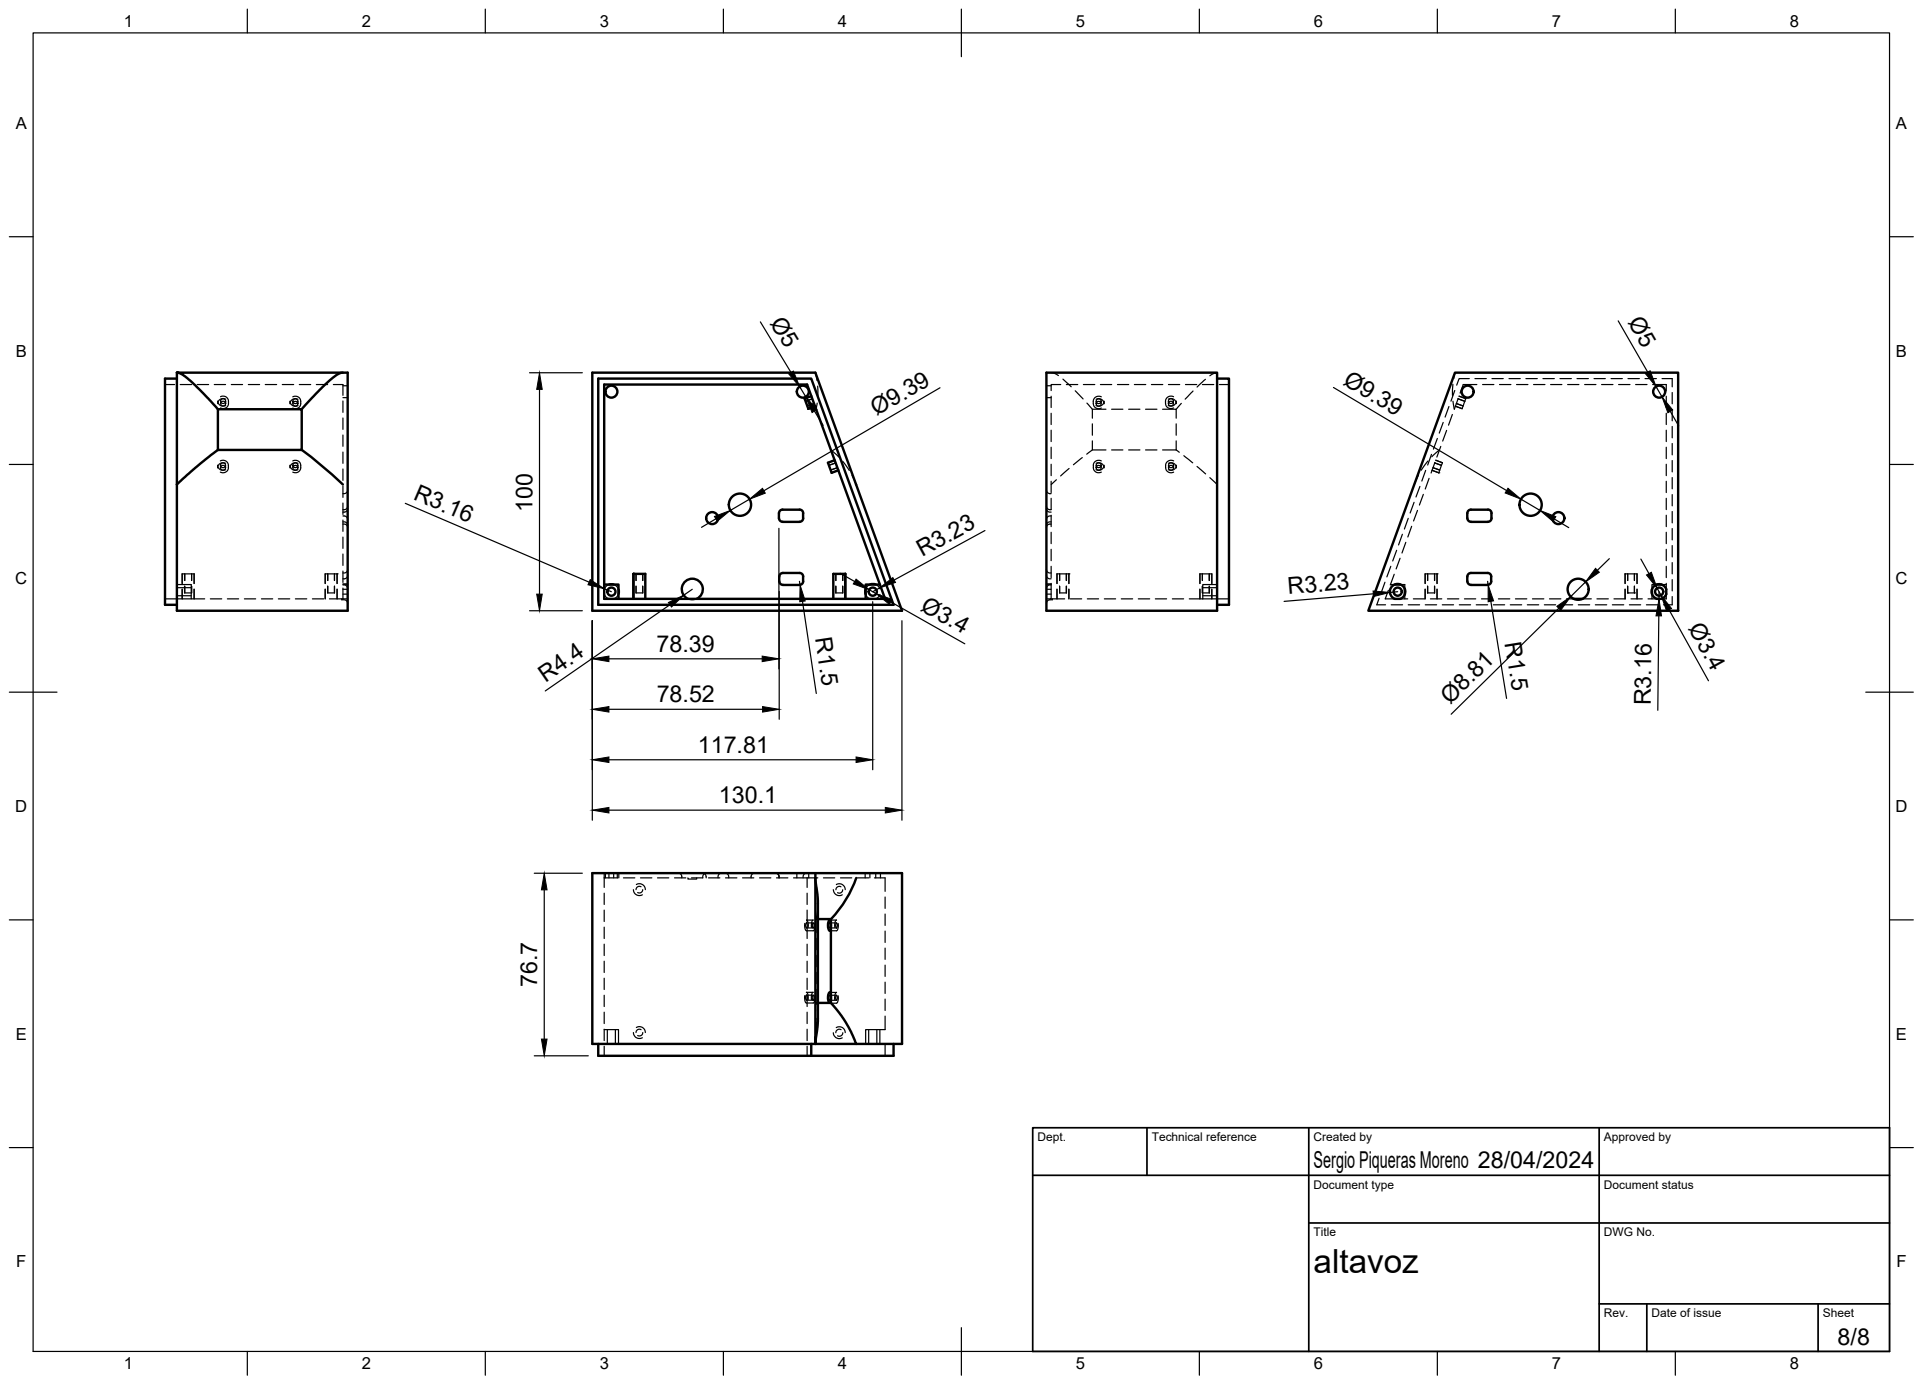
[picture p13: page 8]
Title; DWG No.

Sergio Piqueras Moreno 76.7

Dept. | Technical reference | Created by 28/04/2024 | Approved by

Document type | Document status

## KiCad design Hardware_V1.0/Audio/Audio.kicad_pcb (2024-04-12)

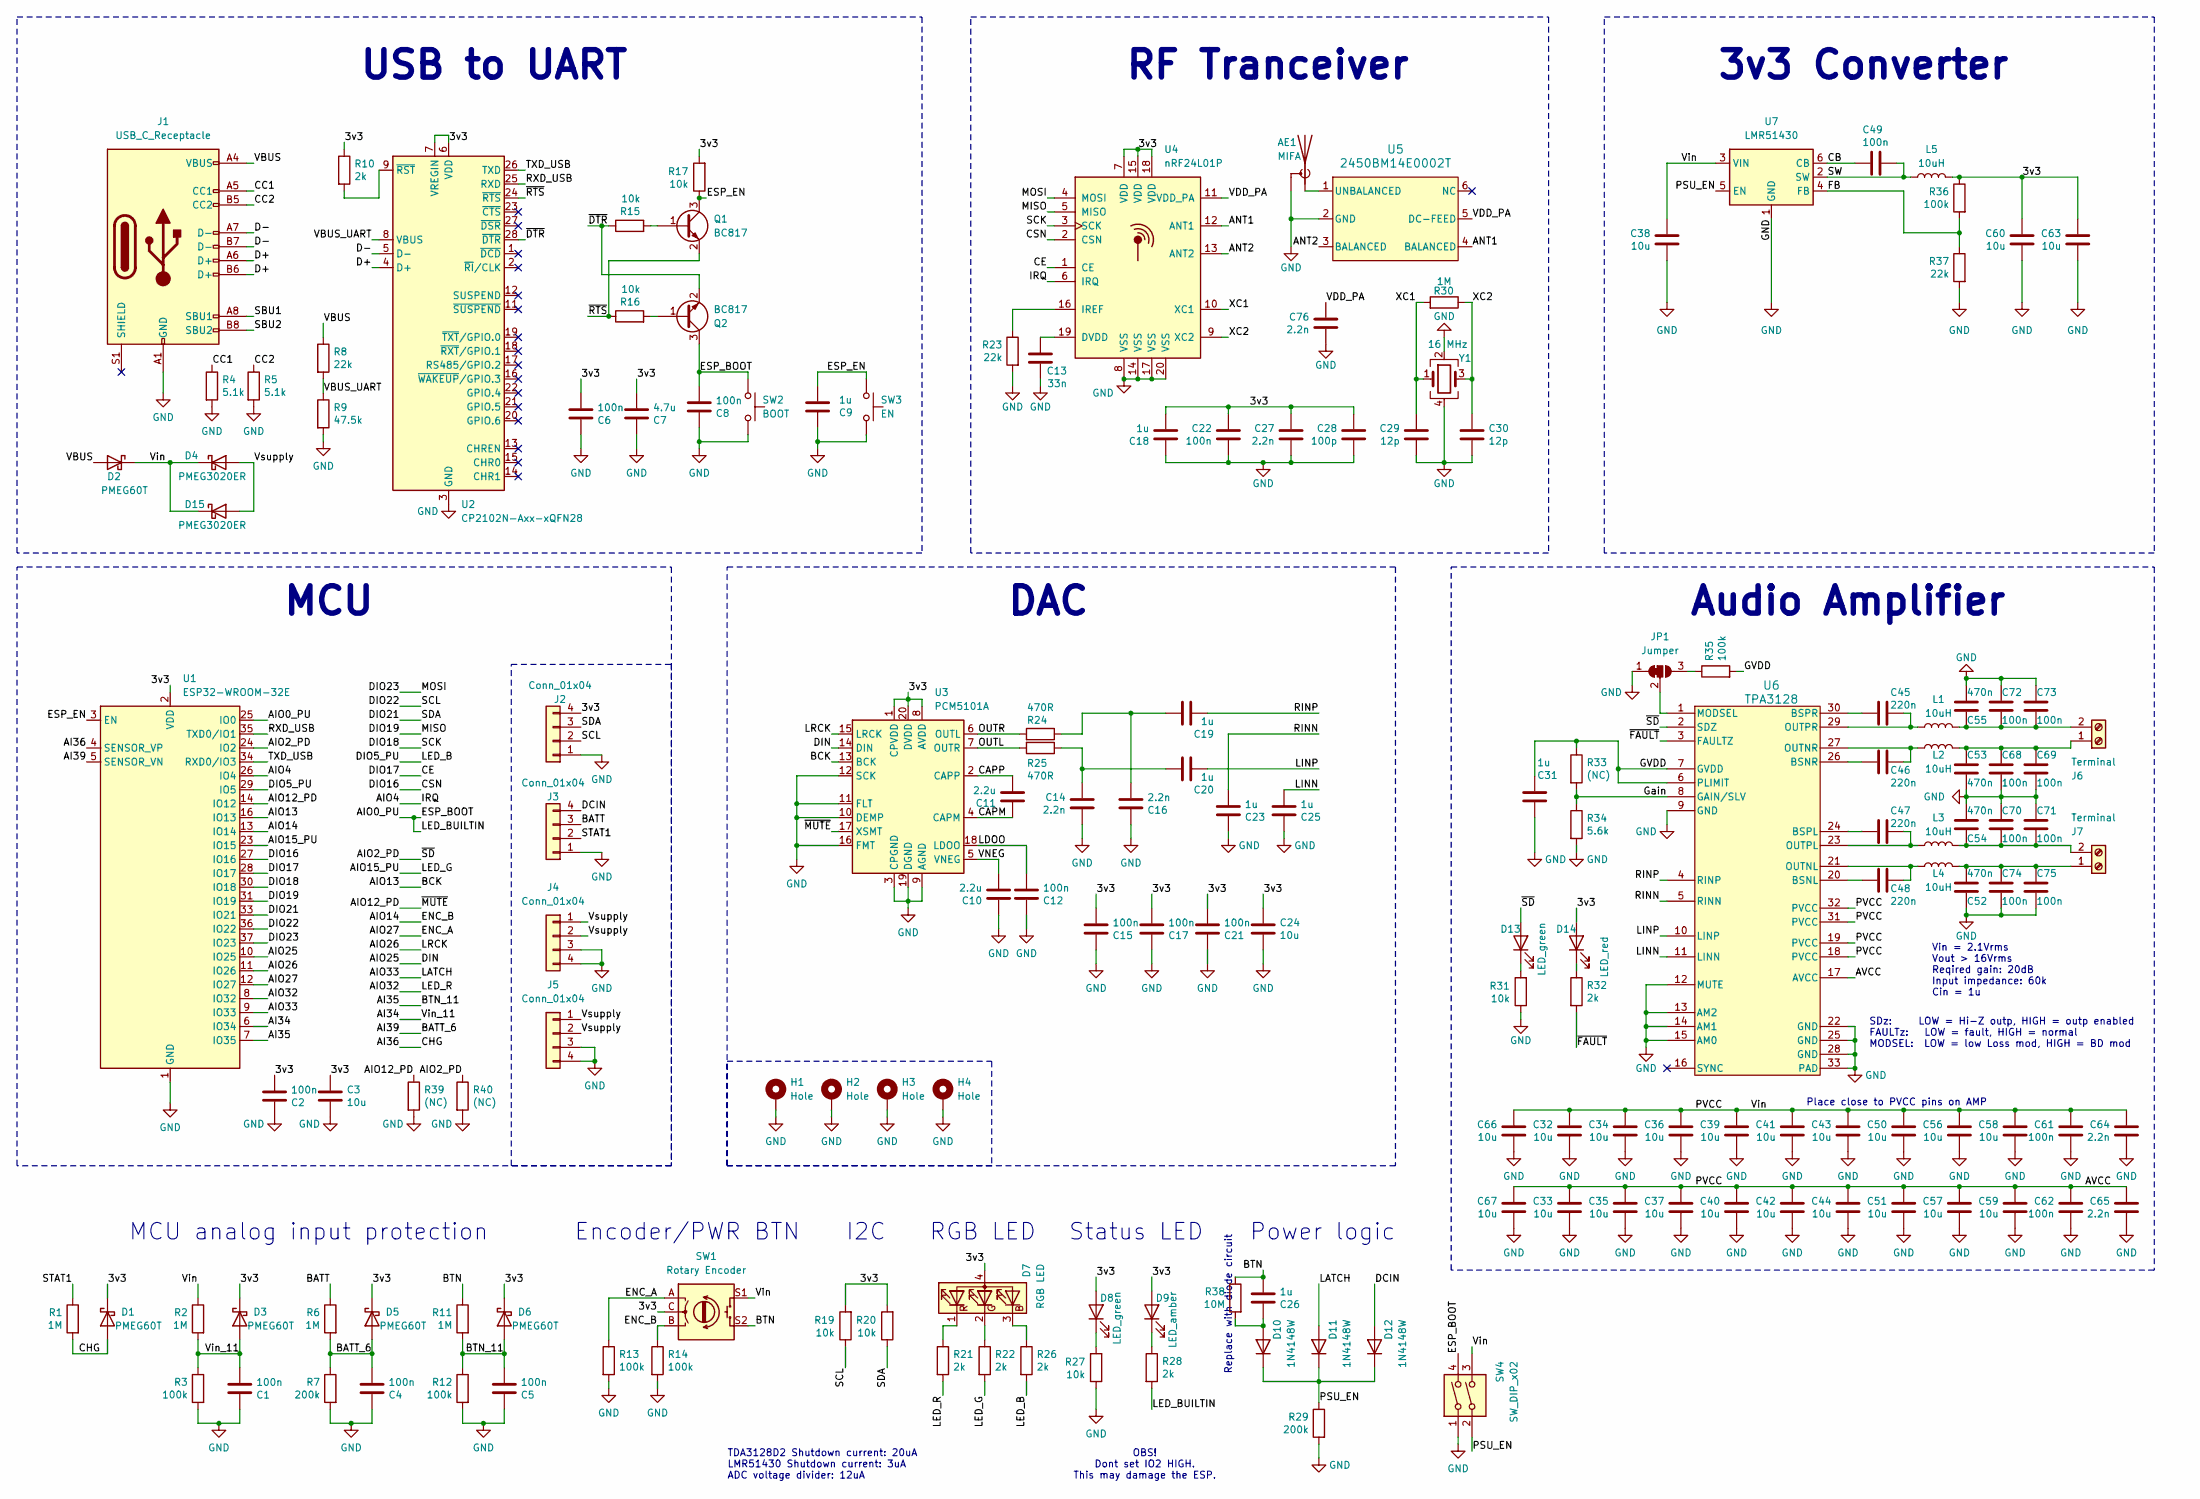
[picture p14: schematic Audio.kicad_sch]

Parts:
AE1: MIFA; Texas_SWRA117D_2.4GHz_Right
C1, C2, C4, C5, C6, C8, C12, C15, C17, C21, C22, C49, C61, C62, C68, C69, C70, C71, C72, C73, C74, C75: 100n; C_0603_1608Metric_Pad1.08x0.95mm_HandSolder; MPN CL10B104JB8NNNC
C3, C24, C32, C33, C34, C35, C36, C37, C38, C39, C40, C41, C42, C43, C44, C50, C51, C56, C57, C58, C59, C60, C63, C66, C67: 10u; C_1206_3216Metric_Pad1.33x1.80mm_HandSolder; MPN CL31B106KBHNNNE
C7: 4.7u; C_0603_1608Metric_Pad1.08x0.95mm_HandSolder; MPN GRM188R6YA475KE15J
C9, C18, C19, C20, C23, C25, C26, C31: 1u; C_0603_1608Metric_Pad1.08x0.95mm_HandSolder; MPN CL10A105KB8NNNC
C10, C11: 2.2u; C_0603_1608Metric_Pad1.08x0.95mm_HandSolder; MPN CL10A225KP8NNNC
C13: 33n; C_0603_1608Metric_Pad1.08x0.95mm_HandSolder; MPN CL10B333KB8NNNC
C14, C16, C27, C64, C65, C76: 2.2n; C_0603_1608Metric_Pad1.08x0.95mm_HandSolder; MPN CL10B222KB8NNND
C28: 100p; C_0603_1608Metric_Pad1.08x0.95mm_HandSolder; MPN CL10C101JB8NNND
C29, C30: 12p; C_0603_1608Metric_Pad1.08x0.95mm_HandSolder; MPN CL10C120JB8NNNC
C45, C46, C47, C48: 220n; C_0603_1608Metric_Pad1.08x0.95mm_HandSolder; MPN CL10B224KB8NNNC
C52, C53, C54, C55: 470n; C_0805_2012Metric_Pad1.18x1.45mm_HandSolder; MPN CL21B474KBFNNNE
D1, D2, D3, D5, D6: PMEG60T; Nexperia_CFP3_SOD-123W; MPN PMEG60T30ELRX
D4, D15: PMEG3020ER; Nexperia_CFP3_SOD-123W; MPN PMEG3020ER,115
D7: RGB LED; RGB_LED
D8, D13: LED_green; LED_0603_1608Metric_Pad1.05x0.95mm_HandSolder; MPN 150060GS75000
D9: LED_amber; LED_0603_1608Metric_Pad1.05x0.95mm_HandSolder; MPN 150060YS75000
D10, D11, D12: 1N4148W; D_SOD-123
D14: LED_red; LED_0603_1608Metric_Pad1.05x0.95mm_HandSolder; MPN 150060RS75000
H1, H2, H3, H4: Hole; MountingHole_3.2mm_M3_DIN965_Pad
J1: USB_C_Receptacle; USB_C_Receptacle_GCT_USB4105-xx-A_16P_TopMnt_Horizontal; MPN USB4105-GF-A-120
J2, J3, J4, J5: Conn_01x04; PinSocket_1x04_P2.54mm_Vertical
J6, J7: Terminal; TerminalBlock_bornier-2_P5.08mm
JP1: Jumper; SolderJumper-3_P1.3mm_Bridged12_RoundedPad1.0x1.5mm
L1, L2, L3, L4, L5: 10uH; 1274AS; MPN DD1274AS-H-100M=P3
Q1, Q2: BC817; SOT-23; MPN BC817-QR
R1, R2, R6, R11, R30: 1M; R_0603_1608Metric_Pad0.98x0.95mm_HandSolder; MPN CRCW06031M00FKEC
R3, R12, R13, R14, R35, R36: 100k; R_0603_1608Metric_Pad0.98x0.95mm_HandSolder; MPN CRCW0603100KFKEA
R4, R5: 5.1k; R_0603_1608Metric_Pad0.98x0.95mm_HandSolder; MPN CRCW06035K10FKEA
R7, R29: 200k; R_0603_1608Metric_Pad0.98x0.95mm_HandSolder; MPN CRCW0603200KFKEA
R8, R23, R37: 22k; R_0603_1608Metric_Pad0.98x0.95mm_HandSolder; MPN CRCW060322K0FKEA
R9: 47.5k; R_0603_1608Metric_Pad0.98x0.95mm_HandSolder; MPN CRCW060347K5FKEA
R10, R21, R22, R26, R28, R32: 2k; R_0603_1608Metric_Pad0.98x0.95mm_HandSolder; MPN CRCW06032K00FKEC
R15, R16, R17, R19, R20, R27, R31: 10k; R_0603_1608Metric_Pad0.98x0.95mm_HandSolder; MPN CRCW060310K0FKEC
R24, R25: 470R; R_0603_1608Metric_Pad0.98x0.95mm_HandSolder; MPN CRCW0603470RFKEA
R33, R39, R40: (NC); R_0603_1608Metric_Pad0.98x0.95mm_HandSolder
R34: 5.6k; R_0603_1608Metric_Pad0.98x0.95mm_HandSolder; MPN CRCW06035K60FKEA
R38: 10M; R_0603_1608Metric_Pad0.98x0.95mm_HandSolder; MPN CRCW060310M0FKEC
SW1: Rotary Encoder; EC11_RotaryEncoder
SW2: BOOT; EVQPUK; MPN EVQ-PUK02K
SW3: EN; EVQPUK; MPN EVQ-PUK02K
SW4: SW_DIP_x02; SW_DIP_SPSTx02_Slide_6.7x6.64mm_W8.61mm_P2.54mm_LowProfile; MPN 219-2MST
U1: ESP32-WROOM-32E; ESP32-WROOM-32D; MPN ESP32-WROOM-32E-N16
U2: CP2102N-Axx-xQFN28; QFN-28-1EP_5x5mm_P0.5mm_EP3.35x3.35mm; MPN CP2102N-A02-GQFN28
U3: PCM5101A; TSSOP-20_4.4x6.5mm_P0.65mm; MPN PCM5101AQPWRQ1
U4: nRF24L01P; QFN-20-1EP_4x4mm_P0.5mm_EP2.5x2.5mm; MPN nRF24L01P
U5: 2450BM14E0002T; 2450BM14E0003T_JOT-L; MPN 2450BM14A0002T
U6: TPA3128; DAP32_4P36X4P11_TEX; MPN TPA3128D2DAPR
U7: LMR51430; SOT-23-6; MPN LMR51430YDDCR
Y1: 16 MHz; Crystal_SMD_2520-4Pin_2.5x2.0mm; MPN ECS-160-10-36-CKM-TR3

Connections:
/3v3: C2.2, C3.1, C6.2, C7.2, C15.2, C17.2, C18.2, C21.2, C22.1, C24.1, C27.1, C28.1, C60.1, C63.1, D1.1 (K), D3.1 (K), D5.1 (K), D6.1 (K), D7.4 (A), D8.2 (A), D9.2 (A), D14.2 (A), J2.4, L5.2, R10.1, R17.2, R19.2, R20.2, R36.1, SW1.C, U1.2 (VDD), U2.6 (VDD), U2.7 (VREGIN), U3.1 (CPVDD), U3.8 (AVDD), U3.20 (DVDD), U4.7 (VDD), U4.15 (VDD), U4.18 (VDD)
/AI34: C1.2, D3.2 (A), R2.2, R3.1, U1.6 (IO34)
/AI35: C5.2, D6.2 (A), R11.2, R12.1, U1.7 (IO35)
/AI36: D1.2 (A), R1.2, U1.4 (SENSOR_VP)
/AI39: C4.2, D5.2 (A), R6.2, R7.1, U1.5 (SENSOR_VN)
/AIO0_PU: C8.2, Q2.3 (C), R28.2, SW2.1, SW4.4, U1.25 (IO0)
/AIO2_PD: D13.2 (A), R40.1, U1.24 (IO2), U6.2 (SDZ)
/AIO4: U1.26 (IO4), U4.6 (IRQ)
/AIO12_PD: R39.1, U1.14 (IO12), U3.17 (XSMT)
/AIO13: U1.16 (IO13), U3.13 (BCK)
/AIO14: R14.1, SW1.B, U1.13 (IO14)
/AIO15_PU: R22.2, U1.23 (IO15)
/AIO25: U1.10 (IO25), U3.14 (DIN)
/AIO26: U1.11 (IO26), U3.15 (LRCK)
/AIO27: R13.1, SW1.A, U1.12 (IO27)
/AIO32: R21.2, U1.8 (IO32)
/AIO33: D11.2 (A), U1.9 (IO33)
/ANT1: U4.12 (ANT1), U5.4 (BALANCED)
/ANT2: U4.13 (ANT2), U5.3 (BALANCED)
/AVCC: C32.1, C33.1, C34.1, C35.1, C36.1, C37.1, C38.1, C39.1, C40.1, C41.1, C42.1, C43.1, C44.1, C50.1, C51.1, C56.1, C57.1, C58.1, C59.1, C61.1, C62.1, C64.1, C65.1, C66.1, C67.1, D2.1 (K), D4.1 (K), D15.1 (K), R2.1, SW1.S1, SW4.3, U6.17 (AVCC), U6.18 (PVCC), U6.19 (PVCC), U6.31 (PVCC), U6.32 (PVCC), U7.3 (VIN)
/BATT: J3.3, R6.1
/BTN: C26.2, R11.1, R38.1, SW1.S2
/CAPM: C11.1, U3.4 (CAPM)
/CAPP: C11.2, U3.2 (CAPP)
/CB: C49.2, U7.6 (CB)
/CC1: J1.A5 (CC1), R4.1
/CC2: J1.B5 (CC2), R5.1
/CE: U1.28 (IO17), U4.1 (CE)
/CSN: U1.27 (IO16), U4.2 (CSN)
/D+: J1.A6 (D+), J1.B6 (D+), U2.4 (D+)
/D-: J1.A7 (D-), J1.B7 (D-), U2.5 (D-)
/DCIN: D12.2 (A), J3.4
/DIO5_PU: R26.2, U1.29 (IO5)
/DIO18: U1.30 (IO18), U4.3 (SCK)
/DIO19: U1.31 (IO19), U4.5 (MISO)
/DIO21: J2.3, R20.1, U1.33 (IO21)
/DIO22: J2.2, R19.1, U1.36 (IO22)
/DIO23: U1.37 (IO23), U4.4 (MOSI)
/ESP_EN: C9.2, Q1.3 (C), R17.1, SW3.1, U1.3 (EN)
/FB: R36.2, R37.1, U7.4 (FB)
/GVDD: C31.2, R33.1, R35.2, U6.6 (PLIMIT), U6.7 (GVDD)
/Gain: R33.2, R34.1, U6.8 (GAIN/SLV)
/LDOO: C12.2, U3.18 (LDOO)
/LINN: C25.2, U6.11 (LINN)
/LINP: C20.2, U6.10 (LINP)
/OUTL: R25.2, U3.7 (OUTR)
/OUTR: R24.2, U3.6 (OUTL)
/PSU_EN: D10.1 (K), D11.1 (K), D12.1 (K), R29.1, SW4.2, U7.5 (EN)
/RINN: C23.2, U6.5 (RINN)
/RINP: C19.2, U6.4 (RINP)
/RXD_USB: U1.35 (TXD0/IO1), U2.25 (RXD)
/SBU1: J1.A8 (SBU1)
/SBU2: J1.B8 (SBU2)
/STAT1: J3.2, R1.1
/SW: C49.1, L5.1, U7.2 (SW)
/TXD_USB: U1.34 (RXD0/IO3), U2.26 (TXD)
/VBUS: D2.2 (A), J1.A4 (VBUS), J1.A9 (VBUS), J1.B4 (VBUS), J1.B9 (VBUS), R8.1
/VBUS_UART: R8.2, R9.1, U2.8 (VBUS)
/VDD_PA: C76.1, U4.11 (VDD_PA), U5.5 (DC-FEED)
/VNEG: C10.2, U3.5 (VNEG)
/Vsupply: D4.2 (A), D15.2 (A), J4.1, J4.2, J5.1, J5.2
/XC1: C29.1, R30.2, U4.10 (XC1), Y1.1
/XC2: C30.1, R30.1, U4.9 (XC2), Y1.3
/~DTR: Q2.2 (E), R15.1, U2.28 (~DTR)
/~FAULT: R32.2, U6.3 (FAULTZ)
/~RTS: Q1.2 (E), R16.1, U2.24 (~RTS)
GND: AE1.2 (Shield), C1.1, C2.1, C3.2, C4.1, C5.1, C6.1, C7.1, C8.1, C9.1, C10.1, C12.1, C13.2, C14.2, C15.1, C16.1, C17.1, C18.1, C21.1, C22.2, C23.1, C24.2, C25.1, C27.2, C28.2, C29.2, C30.2, C31.1, C32.2, C33.2, C34.2, C35.2, C36.2, C37.2, C38.2, C39.2, C40.2, C41.2, C42.2, C43.2, C44.2, C50.2, C51.2, C52.1, C53.1, C54.2, C55.2, C56.2, C57.2, C58.2, C59.2, C60.2, C61.2, C62.2, C63.2, C64.2, C65.2, C66.2, C67.2, C68.1, C69.1, C70.2, C71.2, C72.2, C73.2, C74.1, C75.1, C76.2, H1.1, H2.1, H3.1, H4.1, J1.A1 (GND), J1.A12 (GND), J1.B1 (GND), J1.B12 (GND), J2.1, J3.1, J4.3, J4.4, J5.3, J5.4, JP1.1 (A), R3.2, R4.2, R5.2, R7.2, R9.2, R12.2, R13.2, R14.2, R23.2, R27.1, R29.2, R31.1, R34.2, R37.2, R39.2, R40.2, SW2.2, SW3.2, SW4.1, U1.1 (GND), U1.15 (GND), U1.38 (GND), U1.39 (GND), U2.3 (GND), U2.29 (GND), U3.3 (CPGND), U3.9 (AGND), U3.10 (DEMP), U3.11 (FLT), U3.12 (SCK), U3.16 (FMT), U3.19 (DGND), U4.8 (VSS), U4.14 (VSS), U4.17 (VSS), U4.20 (VSS), U5.2 (GND), U6.9 (GND), U6.12 (MUTE), U6.13 (AM2), U6.14 (AM1), U6.15 (AM0), U6.22 (GND), U6.25 (GND), U6.28 (GND), U6.33 (PAD), U7.1 (GND), Y1.2, Y1.4
unnamed: AE1.1 (A), U5.1 (UNBALANCED)
unnamed: C14.1, C20.1, R25.1
unnamed: C16.2, C19.1, R24.1
unnamed: D7.3 (BK), R26.1
unnamed: D7.2 (GK), R22.1
unnamed: D7.1 (RK), R21.1
unnamed: D8.1 (K), R27.2
unnamed: D9.1 (K), R28.1
unnamed: C26.1, D10.2 (A), R38.2
unnamed: D13.1 (K), R31.2
unnamed: D14.1 (K), R32.1
unnamed: C53.2, C68.2, C69.2, J6.1, L2.1
unnamed: C55.1, C72.1, C73.1, J6.2, L1.2
unnamed: C52.2, C74.2, C75.2, J7.1, L4.1
unnamed: C54.1, C70.1, C71.1, J7.2, L3.2
unnamed: JP1.3 (B), R35.1
unnamed: JP1.2 (C), U6.1 (MODSEL)
unnamed: Q1.1 (B), R15.2
unnamed: Q2.1 (B), R16.2
unnamed: R10.2, U2.9 (~RST)
unnamed: C13.1, U4.19 (DVDD)
unnamed: R23.1, U4.16 (IREF)
unnamed: C48.2, U6.20 (BSNL)
unnamed: C46.2, U6.26 (BSNR)
unnamed: C47.2, U6.24 (BSPL)
unnamed: C45.2, U6.30 (BSPR)
unnamed: C48.1, L4.2, U6.21 (OUTNL)
unnamed: C46.1, L2.2, U6.27 (OUTNR)
unnamed: C47.1, L3.1, U6.23 (OUTPL)
unnamed: C45.1, L1.1, U6.29 (OUTPR)

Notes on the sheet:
TDA3128D2 Shutdown current: 20uA LMR51430 Shutdown current: 3uA ADC voltage divider: 12uA
Audio Amplifier
I2C
Vin = 2.1Vrms Vout > 16Vrms Reqired gain: 20dB Input impedance: 60k Cin = 1u
RGB LED
MCU
Power logic
Place close to PVCC pins on AMP
DAC
OBS! Dont set IO2 HIGH. This may damage the ESP.
Status LED
MCU analog input protection
USB to UART
RF Tranceiver
Replace with diode circuit
Encoder/PWR BTN
3v3 Converter
SDz: LOW = Hi-Z outp, HIGH = outp enabled FAULTz: LOW = fault, HIGH = normal MODSEL: LOW = low Loss mod, HIGH = BD mod

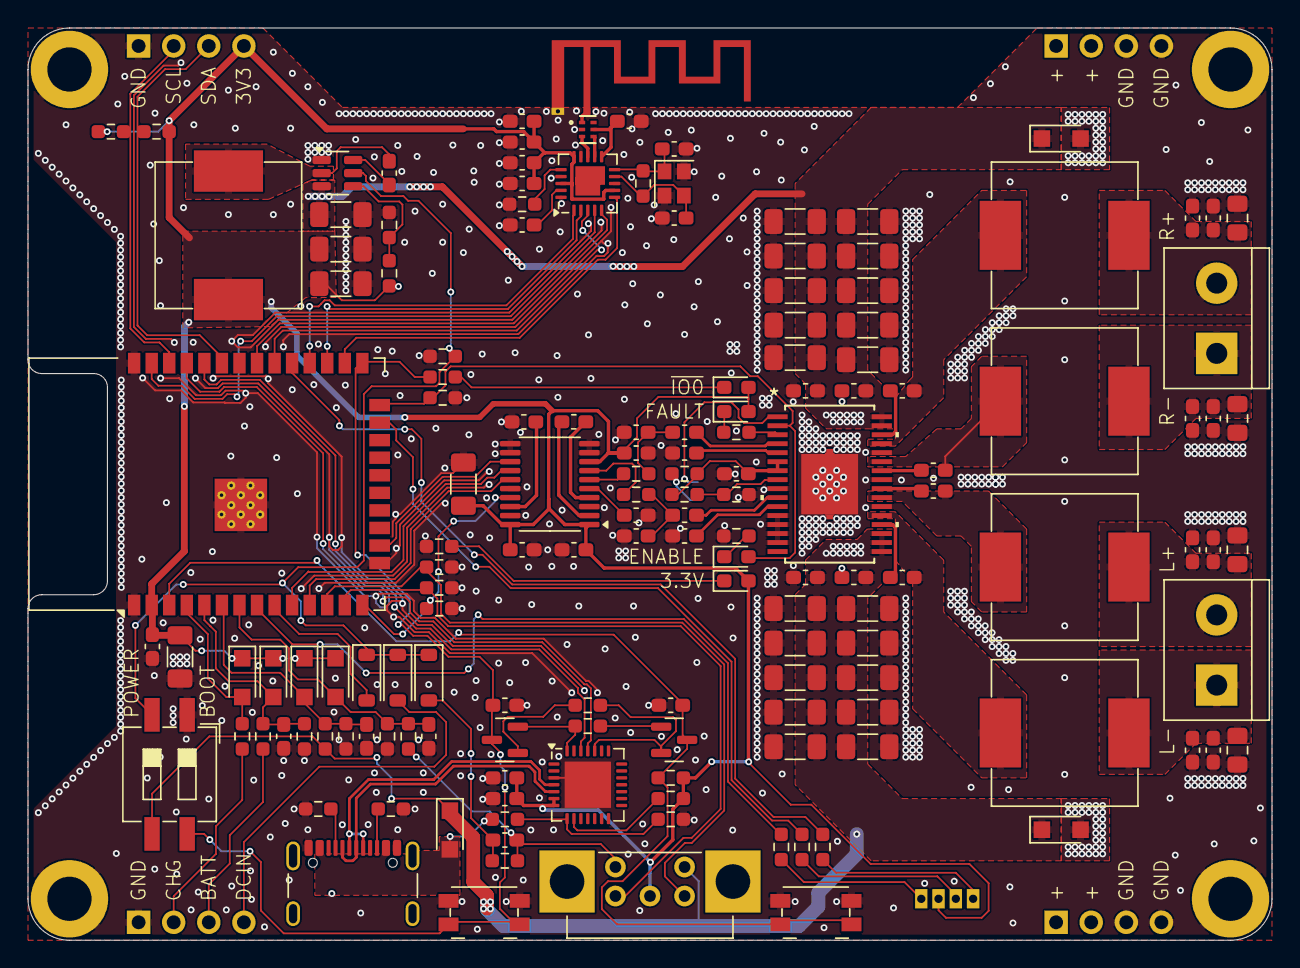
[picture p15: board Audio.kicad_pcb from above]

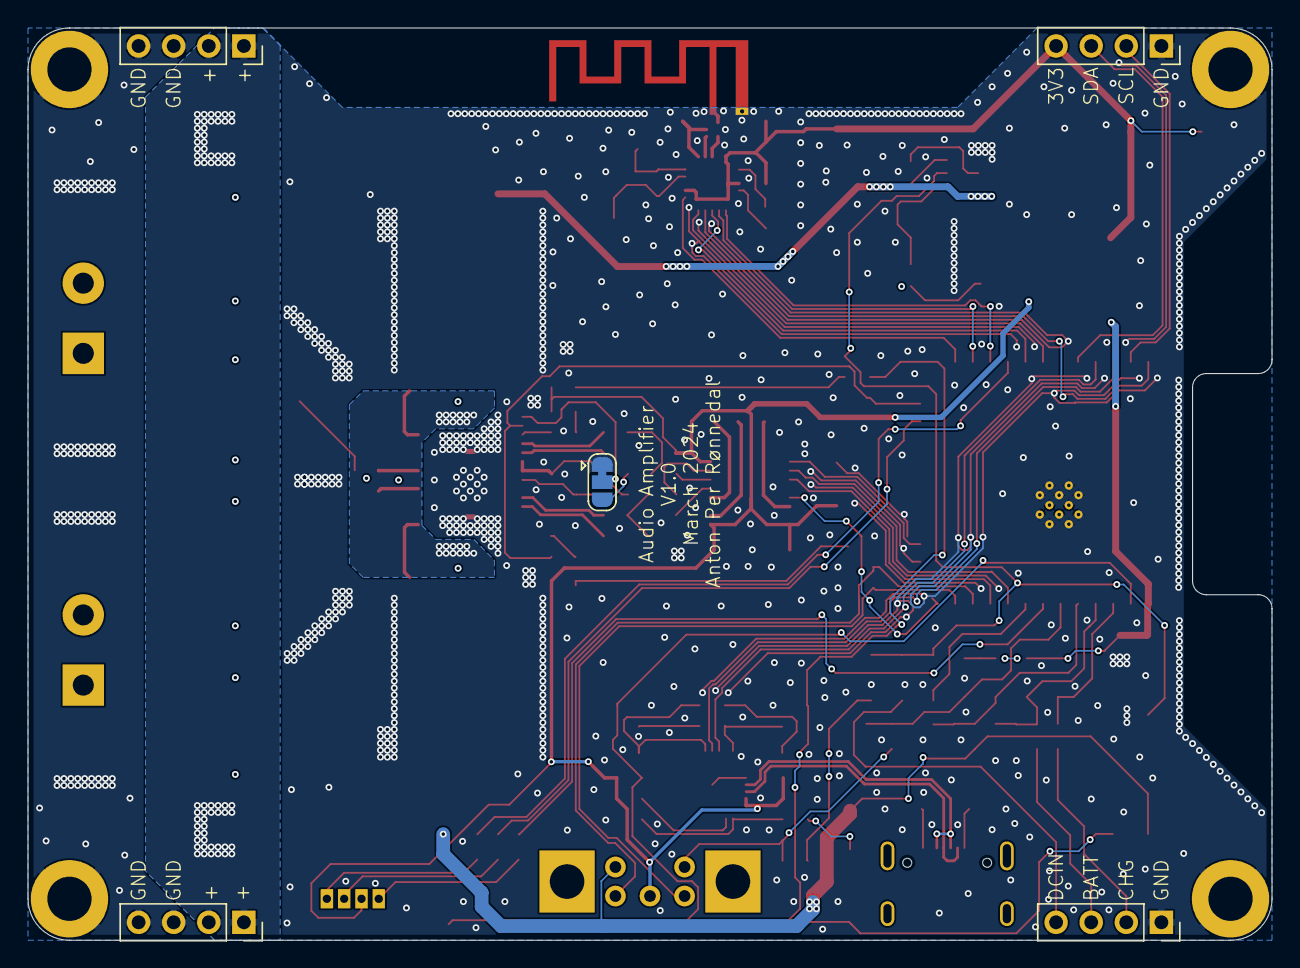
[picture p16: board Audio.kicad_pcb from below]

Board: 4 copper layers, 90.0 x 66.0 mm, 162 parts (5 on the bottom side), 95 nets.

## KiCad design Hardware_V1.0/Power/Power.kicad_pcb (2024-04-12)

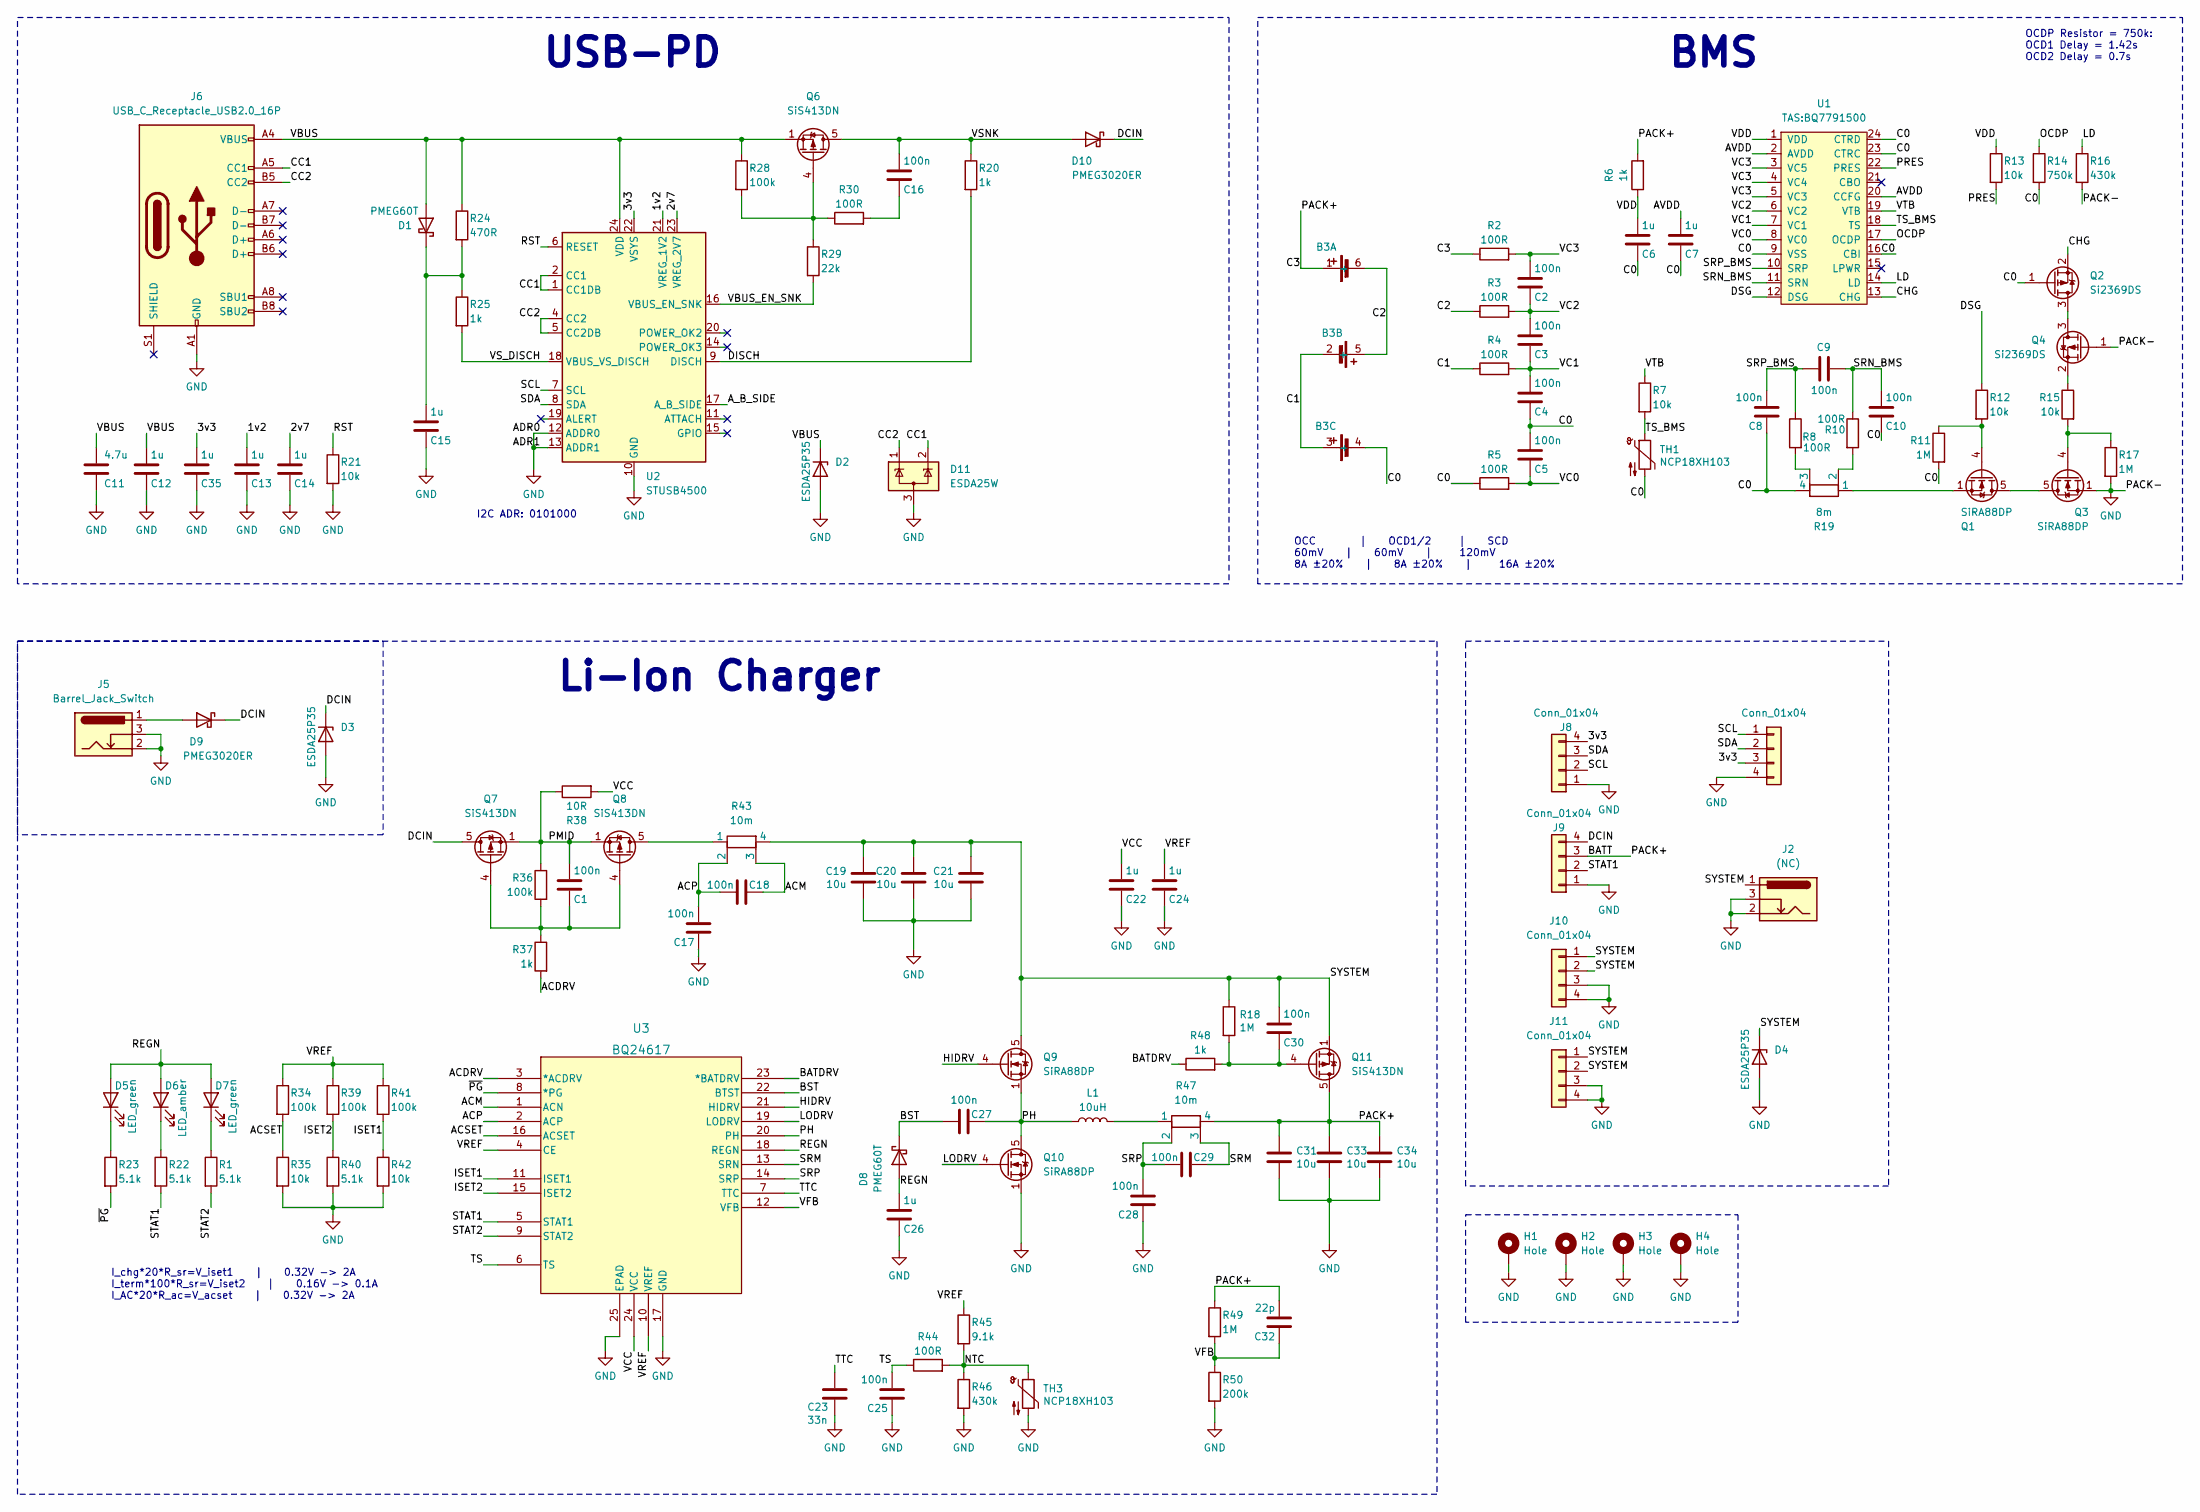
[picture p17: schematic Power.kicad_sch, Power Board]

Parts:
B3: BLM_18650x3
C1, C2, C3, C4, C5, C8, C9, C10, C16, C17, C18, C25, C27, C28, C29, C30: 100n; C_0603_1608Metric_Pad1.08x0.95mm_HandSolder; MPN CL10B104JB8NNNC
C6, C7, C12, C13, C14, C15, C22, C24, C26, C35: 1u; C_0603_1608Metric_Pad1.08x0.95mm_HandSolder; MPN CL10A105KB8NNNC
C11: 4.7u; C_0603_1608Metric_Pad1.08x0.95mm_HandSolder; MPN GRM188R6YA475KE15J
C19, C20, C21, C31, C33, C34: 10u; C_1206_3216Metric_Pad1.33x1.80mm_HandSolder; MPN CL31B106KBHNNNE
C23: 33n; C_0603_1608Metric_Pad1.08x0.95mm_HandSolder; MPN CL10B333KB8NNNC
C32: 22p; C_0603_1608Metric_Pad1.08x0.95mm_HandSolder; MPN CL10C220JB8NNNC
D1, D8: PMEG60T; Nexperia_CFP3_SOD-123W; MPN PMEG60T30ELRX
D2, D3, D4: ESDA25P35; QFN1610_STM-L; MPN ESDA25P35-1U1M
D5, D7: LED_green; LED_0603_1608Metric_Pad1.05x0.95mm_HandSolder; MPN 150060GS75000
D6: LED_amber; LED_0603_1608Metric_Pad1.05x0.95mm_HandSolder; MPN 150060YS75000
D9, D10: PMEG3020ER; Nexperia_CFP3_SOD-123W; MPN PMEG3020ER,115
D11: ESDA25W; SOT-323_SC-70_Handsoldering; MPN ESDA25W
H1, H2, H3, H4: Hole; MountingHole_3.2mm_M3_DIN965_Pad
J1: Conn_01x04; JST_PH_S4B-PH-SM4-TB_1x04-1MP_P2.00mm_Horizontal; MPN 4392
J2: (NC); BarrelJack_Wuerth_694106106102_2.0x5.5mm; MPN 694106106102
J5: Barrel_Jack_Switch; BarrelJack_Wuerth_694106106102_2.0x5.5mm; MPN 694106106102
J6: USB_C_Receptacle_USB2.0_16P; USB_C_Receptacle_GCT_USB4105-xx-A_16P_TopMnt_Horizontal; MPN USB4105-GF-A-120
J8, J9, J10, J11: Conn_01x04; PinSocket_1x04_P2.54mm_Vertical
L1: 10uH; 1274AS; MPN DD1274AS-H-100M=P3
Q1, Q3, Q9, Q10: SiRA88DP; PowerPAK_SO-8_Single; MPN SIRA88DP-T1-GE3
Q2, Q4: Si2369DS; SOT-23; MPN SI2369DS-T1-GE3
Q6, Q7, Q8, Q11: SiS413DN; Vishay_PowerPAK_1212-8_Single; MPN SIS413DN-T1-GE3
R1, R22, R23, R40: 5.1k; R_0603_1608Metric_Pad0.98x0.95mm_HandSolder; MPN CRCW06035K10FKEA
R2, R3, R4, R5, R8, R10, R30, R44: 100R; R_0603_1608Metric_Pad0.98x0.95mm_HandSolder; MPN CRCW0603100RFKEC
R6, R20, R25, R37, R48: 1k; R_0603_1608Metric_Pad0.98x0.95mm_HandSolder; MPN CRCW06031K00FKEC
R7, R12, R13, R15, R21, R35, R42: 10k; R_0603_1608Metric_Pad0.98x0.95mm_HandSolder; MPN CRCW060310K0FKEC
R11, R17, R18, R49: 1M; R_0603_1608Metric_Pad0.98x0.95mm_HandSolder; MPN CRCW06031M00FKEC
R14: 750k; R_0603_1608Metric_Pad0.98x0.95mm_HandSolder; MPN CRCW0603750KFKEA
R16, R46: 430k; R_0603_1608Metric_Pad0.98x0.95mm_HandSolder; MPN CRCW0603430KFKEA
R19: 8m; SenseResistor_1206; MPN MSMA1206R0080FCM
R24: 470R; R_0603_1608Metric_Pad0.98x0.95mm_HandSolder; MPN CRCW0603470RFKEC
R28, R34, R36, R39, R41: 100k; R_0603_1608Metric_Pad0.98x0.95mm_HandSolder; MPN CRCW0603100KFKEA
R29: 22k; R_0603_1608Metric_Pad0.98x0.95mm_HandSolder; MPN CRCW060322K0FKEA
R38: 10R; R_0603_1608Metric_Pad0.98x0.95mm_HandSolder; MPN CRCW060310R0FKEC
R43, R47: 10m; SenseResistor_1206; MPN MFSA1206R0100FCM
R45: 9.1k; R_0603_1608Metric_Pad0.98x0.95mm_HandSolder; MPN CRCW06039K10FKEA
R50: 200k; R_0603_1608Metric_Pad0.98x0.95mm_HandSolder; MPN CRCW0603200KFKEA
TH1, TH3: NCP18XH103; R_0603_1608Metric_Pad0.98x0.95mm_HandSolder; MPN NCP18XH103F03RB
U1: TAS:BQ7791500; TSSOP-24_4.4x7.8mm_P0.65mm; MPN BQ7791500PWR
U2: STUSB4500; QFN-24-1EP_4x4mm_P0.5mm_EP2.7x2.7mm; MPN STUSB4500QTR
U3: BQ24617; QFN-24-1EP_4x4mm_P0.5mm_EP2.15x2.15mm_ThermalVias; MPN BQ24617RGER

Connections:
/1v2: C13.1, U2.21 (VREG_1V2)
/2v7: C14.1, U2.23 (VREG_2V7)
/3v3: C35.1, J1.3, J8.4, U2.22 (VSYS)
/ACDRV: R37.2, U3.3 (*ACDRV)
/ACM: C18.2, R43.3, U3.1 (ACN)
/ACP: C17.1, C18.1, R43.2, U3.2 (ACP)
/ACSET: R34.2, R35.1, U3.16 (ACSET)
/AVDD: C7.1, U1.2 (AVDD), U1.20 (CCFG)
/A_B_SIDE: U2.17 (A_B_SIDE)
/BATDRV: R48.1, U3.23 (*BATDRV)
/BATT: B3.1 (+), C31.1, C32.1, C33.1, C34.1, J9.3, Q11.5 (D), R2.1, R6.2, R47.4, R49.1
/BST: C27.1, D8.1 (K), U3.22 (BTST)
/C0: B3.4 (-), C4.2, C5.1, C6.2, C7.2, C8.2, C10.2, Q2.1 (G), R5.1, R11.2, R14.2, R19.4, TH1.2, U1.9 (VSS), U1.16 (CBI), U1.23 (CTRC), U1.24 (CTRD)
/C1: B3.2 (-), B3.3 (+), R4.1
/C2: B3.5 (+), B3.6 (-), R3.1
/CC1: D11.2 (K), J6.A5 (CC1), U2.1 (CC1DB), U2.2 (CC1)
/CC2: D11.1 (K), J6.B5 (CC2), U2.4 (CC2), U2.5 (CC2DB)
/CHG: Q2.2 (S), U1.13 (CHG)
/DCIN: D3.1 (K), D9.1 (K), D10.1 (K), J9.4, Q7.5 (D)
/DISCH: R20.2, U2.9 (DISCH)
/DSG: R12.1, U1.12 (DSG)
/HIDRV: Q9.4 (G), U3.21 (HIDRV)
/ISET1: R41.2, R42.1, U3.11 (ISET1)
/ISET2: R39.2, R40.1, U3.15 (ISET2)
/LD: R16.1, U1.14 (LD)
/LODRV: Q10.4 (G), U3.19 (LODRV)
/NTC: R44.2, R45.2, R46.1, TH3.1
/OCDP: R14.1, U1.17 (OCDP)
/PH: C27.2, L1.2, Q9.1 (S), Q9.2 (S), Q9.3 (S), Q10.5 (D), U3.20 (PH)
/PMID: C1.1, Q7.1 (S), Q7.2 (S), Q7.3 (S), Q8.1 (S), Q8.2 (S), Q8.3 (S), R36.1, R38.1
/PRES: R13.2, U1.22 (PRES)
/REGN: C26.1, D5.2 (A), D6.2 (A), D7.2 (A), D8.2 (A), U3.18 (REGN)
/RST: R21.1, U2.6 (RESET)
/SCL: J1.1, J8.2, U2.7 (SCL)
/SDA: J1.2, J8.3, U2.8 (SDA)
/SRM: C29.2, R47.3, U3.13 (SRN)
/SRN_BMS: C9.2, C10.1, R10.1, U1.11 (SRN)
/SRP: C28.1, C29.1, R47.2, U3.14 (SRP)
/SRP_BMS: C8.1, C9.1, R8.1, U1.10 (SRP)
/STAT1: J9.2, R22.2, U3.5 (STAT1)
/STAT2: R1.2, U3.9 (STAT2)
/SYSTEM: C19.1, C20.1, C21.1, C30.1, D4.1 (K), J2.1, J10.1, J10.2, J11.1, J11.2, Q9.5 (D), Q11.1 (S), Q11.2 (S), Q11.3 (S), R18.1, R43.4
/TS: C25.1, R44.1, U3.6 (TS)
/TS_BMS: R7.2, TH1.1, U1.18 (TS)
/TTC: C23.1, U3.7 (TTC)
/VBUS: C11.2, C12.1, D1.2 (A), D2.1 (K), J6.A4 (VBUS), J6.A9 (VBUS), J6.B4 (VBUS), J6.B9 (VBUS), Q6.1 (S), Q6.2 (S), Q6.3 (S), R24.1, R28.1, U2.24 (VDD)
/VBUS_EN_SNK: R29.2, U2.16 (VBUS_EN_SNK)
/VC0: C5.2, R5.2, U1.8 (VC0)
/VC1: C3.2, C4.1, R4.2, U1.7 (VC1)
/VC2: C2.2, C3.1, R3.2, U1.6 (VC2)
/VC3: C2.1, R2.2, U1.3 (VC5), U1.4 (VC4), U1.5 (VC3)
/VCC: C22.1, R38.2, U3.24 (VCC)
/VDD: C6.1, R6.1, R13.1, U1.1 (VDD)
/VFB: C32.2, R49.2, R50.1, U3.12 (VFB)
/VREF: C24.1, R34.1, R39.1, R41.1, R45.1, U3.4 (CE), U3.10 (VREF)
/VSNK: C16.1, D10.2 (A), Q6.5 (D), R20.1
/VS_DISCH: R25.2, U2.18 (VBUS_VS_DISCH)
/VTB: R7.1, U1.19 (VTB)
/~PG: R23.2, U3.8 (*PG)
GND: C11.1, C12.2, C13.2, C14.2, C15.2, C17.2, C19.2, C20.2, C21.2, C22.2, C23.2, C24.2, C25.2, C26.2, C28.2, C31.2, C33.2, C34.2, C35.2, D2.2 (A), D3.2 (A), D4.2 (A), D11.3 (A), H1.1, H2.1, H3.1, H4.1, J1.4, J2.2, J2.3, J5.2, J5.3, J6.A1 (GND), J6.A12 (GND), J6.B1 (GND), J6.B12 (GND), J8.1, J9.1, J10.3, J10.4, J11.3, J11.4, Q3.1 (S), Q3.2 (S), Q3.3 (S), Q4.1 (G), Q10.1 (S), Q10.2 (S), Q10.3 (S), R16.2, R17.2, R21.2, R35.2, R40.2, R42.2, R46.2, R50.2, TH3.2, U2.10 (GND), U2.12 (ADDR0), U2.13 (ADDR1), U2.25 (GND), U3.17 (GND), U3.25 (EPAD)
unnamed: C16.2, R30.2
unnamed: C15.1, D1.1 (K), R24.2, R25.1
unnamed: D5.1 (K), R23.1
unnamed: D6.1 (K), R22.1
unnamed: D7.1 (K), R1.1
unnamed: D9.2 (A), J5.1
unnamed: L1.1, R47.1
unnamed: Q1.5 (D), Q3.5 (D)
unnamed: Q1.4 (G), R11.1, R12.2
unnamed: Q1.1 (S), Q1.2 (S), Q1.3 (S), R19.1
unnamed: Q2.3 (D), Q4.3 (D)
unnamed: Q3.4 (G), R15.2, R17.1
unnamed: Q4.2 (S), R15.1
unnamed: Q6.4 (G), R28.2, R29.1, R30.1
unnamed: C1.2, Q7.4 (G), Q8.4 (G), R36.2, R37.1
unnamed: Q8.5 (D), R43.1
unnamed: C30.2, Q11.4 (G), R18.2, R48.2
unnamed: R10.2, R19.2
unnamed: R8.2, R19.3

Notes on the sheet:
Li-Ion Charger
I_chg*20*R_sr=V_iset1 | 0.32V -> 2A I_term*100*R_sr=V_iset2 | 0.16V -> 0.1A I_AC*20*R_ac=V_acset | 0.32V -> 2A
USB-PD
OCDP Resistor = 750k: OCD1 Delay = 1.42s OCD2 Delay = 0.7s
I2C ADR: 0101000
OCC | OCD1/2 | SCD 60mV | 60mV | 120mV 8A ±20% | 8A ±20% | 16A ±20%
BMS

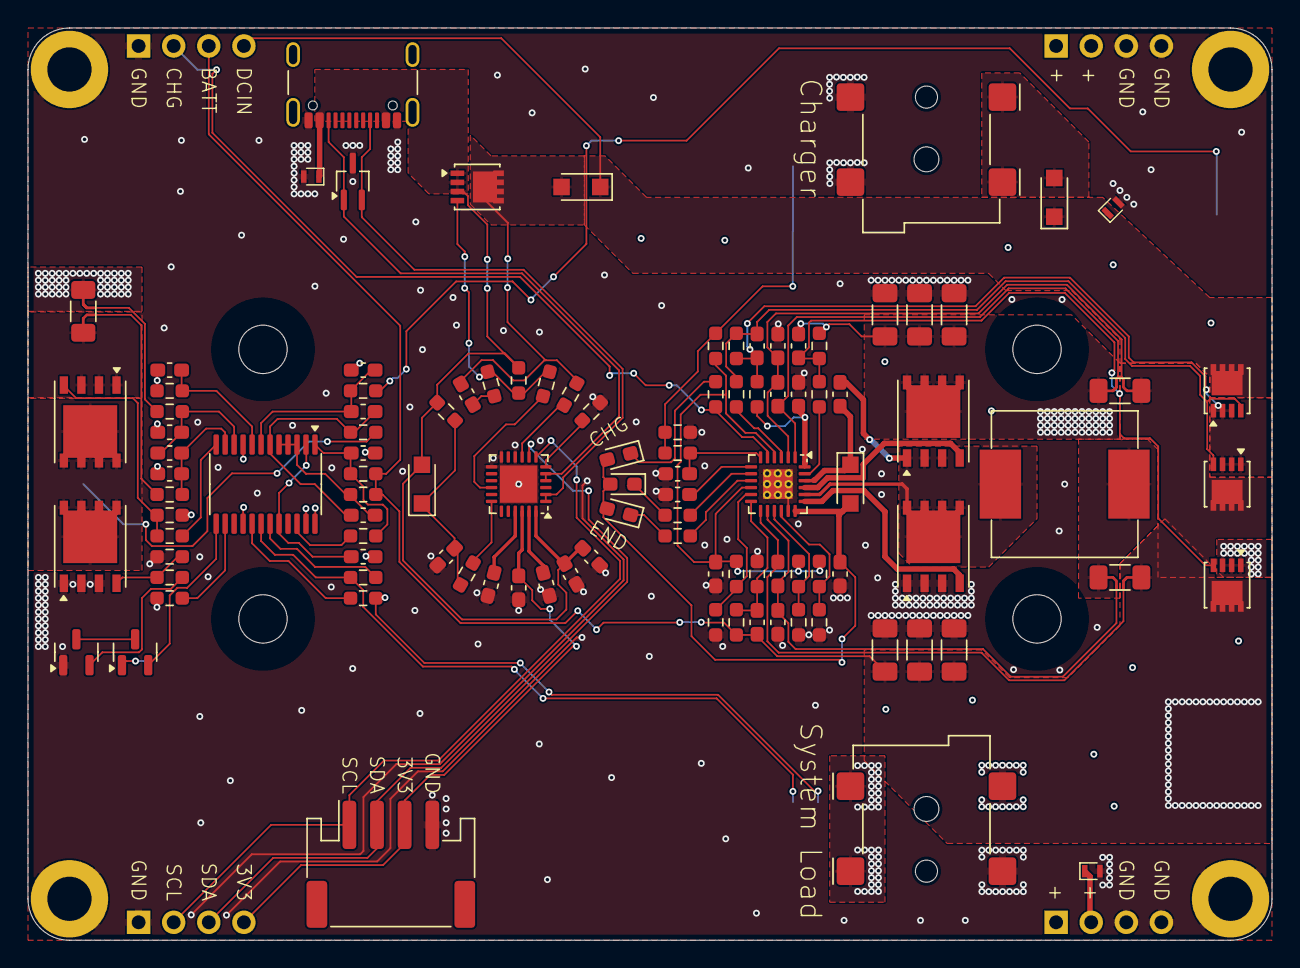
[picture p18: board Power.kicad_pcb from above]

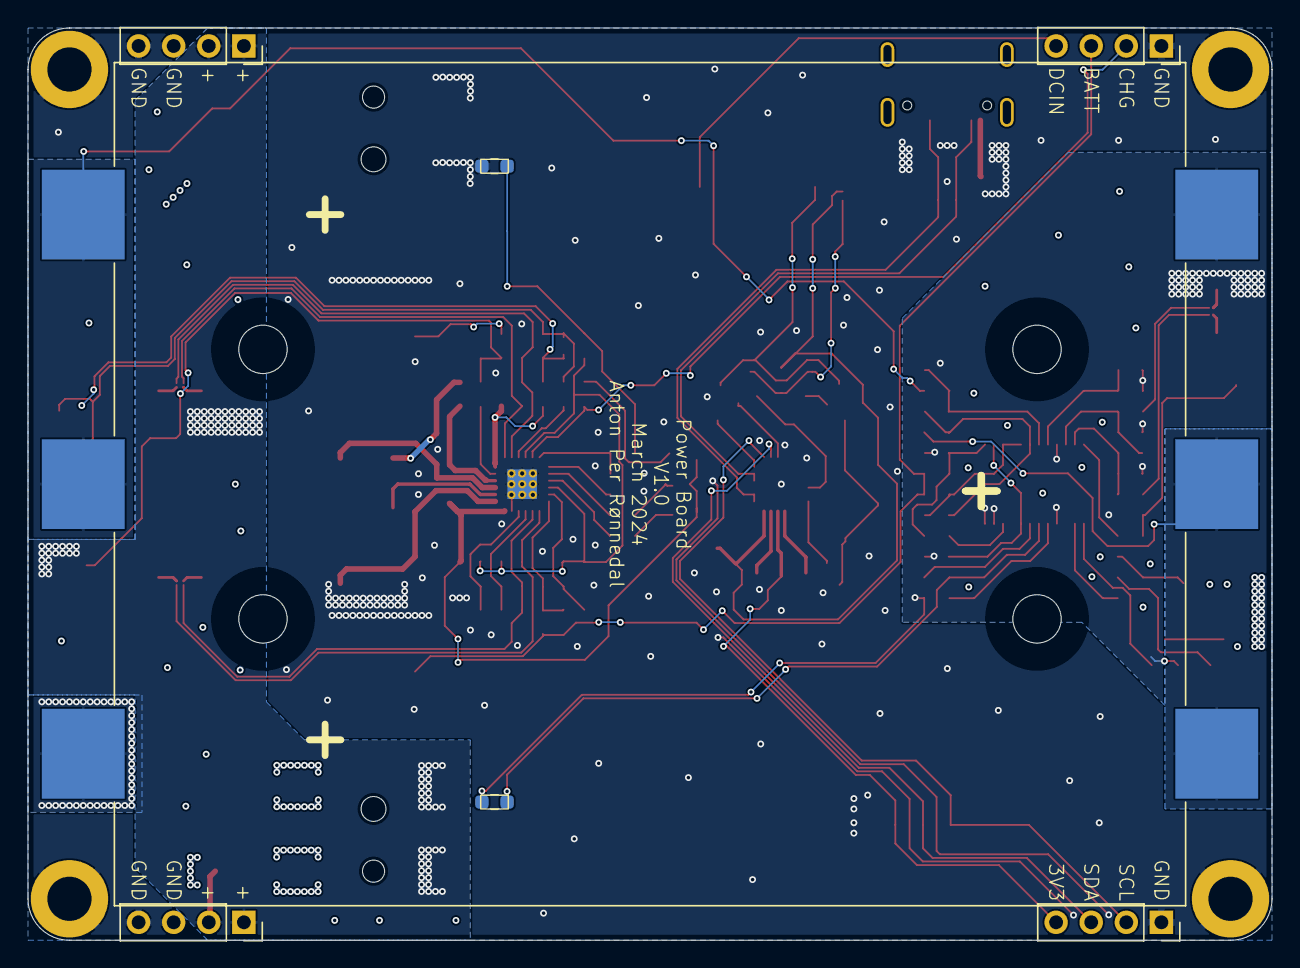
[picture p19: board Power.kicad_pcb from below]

Board: 4 copper layers, 90.0 x 66.0 mm, 119 parts (11 on the bottom side), 78 nets.

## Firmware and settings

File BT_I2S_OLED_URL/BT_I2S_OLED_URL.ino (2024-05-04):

#include "BluetoothA2DPSink.h"
#include <Wire.h>
#include <Adafruit_SH110X.h>
#include <Adafruit_GFX.h>
#include "WifiCredentials.h"
#include "Audio.h"
#include <EEPROM.h>
#define _TIMERINTERRUPT_LOGLEVEL_     3
#include "ESP32_New_TimerInterrupt.h"
#include <RF24.h>
#include <RF24Network.h>

/*
* Description:
* This is code for the Soundwich Bluetooth/WiFi speaker project by Group 7 in the IoT course at DTU.
*
* This is the final project in the 34346 Networking technologies and application development for the Internet of Things (IoT) at DTU
*
* The project was made by:
* Alexander Nordentoft - s176361
* Andreas Nielsen - s203833
* Anton Per Rønnedal - s203821
* Rasmus Kurdahl-Martinsen - s194337
* Sergio Piqueras Moreno - s232104
* 
* This project would not have worked without the work done by Ernst Sikora on his M5StickC_WebRadio project.
* https://github.com/esikora/M5StickC_WebRadio
* The base structure of the code and the handling of A2DP and WiFi is based on his work.
* 
* To connect to WiFi, the user should create their own WiFiCredentials.cpp file with contents as described in WifiCredentials.h
*/


//#define DEBUG //Uncomment to enable debug messages

//NRF PINS
#define PIN_NRF_CE 17
#define PIN_NRF_CSN 16
#define PIN_NRF_IRQ 4
#define PIN_NRF_MISO 19
#define PIN_NRF_MOSI 23
#define PIN_NRF_SCK 18

//I2S PINS & INFO
#define I2S_BCK_PIN 13
#define I2S_WS_PIN 26
#define I2S_DOUT_PIN 25
#define SAMPLE_RATE 44100
#define BITS 16
#define CHANNELS 2

//LED & BUTTON PINS
#define PIN_LED 0
#define PIN_BTN 35
#define PIN_ENC_A 27
#define PIN_ENC_B 14
#define PIN_LED_R 32
#define PIN_LED_G 15
#define PIN_LED_B 5

//I2C PINS
#define PIN_I2C_SDA 21
#define PIN_I2C_SCL 22

//AMP & PSU PINS
#define PIN_AMP_EN 2
#define PIN_PSU_EN 33
#define PD_MUTE 12

//Power Delivery I2C Address & Frequency
#define PD_I2C_ADR  0x28   //0101000
#define PD_I2C_FREQ 100000 //kb/s

//Timer intervals
#define TIMER_0_INTERVAL 1000000 //Blink & Tick interval (µs)
#define TIMER_3_INTERVAL 50000 //Power button refresh rate (µs)

//PWM settings
#define PWM_FREQ 5000 //Hz
#define PWM_CNL_R 0 //Channel (0-16)
#define PWM_CNL_G 1 
#define PWM_CNL_B 3 
#define PWM_RES 8 //Resoluion (0-16 Bit)

//Encoder settings
#define ENC_VEL 5 //Encoder velocity
#define SW_THRESHOLD 300

#define BTN_SINGLE_PRESS 20
#define BTN_LONG_PRESS 100

//Battery & Charging
#define PIN_BATT 39
#define PIN_CHG 36

//Timer objects
ESP32Timer Timer0(0); //4 timers are available (from 0 to 3)
ESP32Timer Timer3(3);

//Struct to hold metadata
struct Metadata {
  char title[100];
  char artist[100];
  char album[100];
};

//Device name - used for Bluetooth
const char* deviceName = "Soundwich";

//Max volume, based on 7-bit volume control from Bluetooth
const uint8_t volumeMax = 127;

//Volume control variables
static volatile char ENC_COUNT = 0;
static volatile long tick = 0; //Seconds from power on
static volatile bool encA = false;
static volatile bool encB = false;

// /*Interrupt Handlers*/
bool IRAM_ATTR Timer0_ISR(void * timerNo);
bool IRAM_ATTR Timer3_ISR(void * timerNo);
void IRAM_ATTR encA_ISR();
void IRAM_ATTR encB_ISR();

//128x64 display
#define SCREEN_WIDTH 128
#define SCREEN_HEIGHT 64
Adafruit_SH1106G display(SCREEN_WIDTH, SCREEN_HEIGHT, &Wire, -1);

//Initialize NRF Network
//#define MAX_PAYLOAD_SIZE   144 //Change this value to allow larger payloads for nRFNetwork 
RF24 nrfLink(PIN_NRF_CE, PIN_NRF_CSN);
int8_t channel = 0x76;
RF24Network nrfNetwork(nrfLink);
const uint16_t thisNode = 01;
const uint16_t otherNode = 00;


//TEST STATIONS, Radio BOB is loaded as default because we like it. The rest are left in for use when debugging is active.
/** Web radio stream URLs */
const String stationURLs[] = {
    "http://streams.radiobob.de/bob-national/mp3-192/streams.radiobob.de/",
    "http://stream.rockantenne.de/rockantenne/stream/mp3",
    "http://wdr-wdr2-ruhrgebiet.icecast.wdr.de/wdr/wdr2/ruhrgebiet/mp3/128/stream.mp3",
    "http://streams.br.de/bayern3_2.m3u",
    "http://play.antenne.de/antenne.m3u",
    "http://funkhaus-ingolstadt.stream24.net/radio-in.mp3"
};

/** Number of stations */
const uint8_t numStations = sizeof(stationURLs) / sizeof(stationURLs[0]);

Audio *pAudio_ = nullptr;
TaskHandle_t pAudioTask_ = nullptr;


Metadata metadata;

/**
 * Instance of the 'BluetoothA2DPSink' class from the 'ESP32-A2DP' library.
 * Using a pointer and dynamic creation of the instance causes the ESP32 to crash when a2dp_.start() is called.
 */ 
BluetoothA2DPSink a2dp_;

// Enumeration with possible device modes
enum DeviceMode {WIFI = 0, BT = 1, CHG = 2, NONE = 3, BOOT = 4};

typedef enum DeviceMode t_DeviceMode;

// Current device mode (initialization as 'NONE')
t_DeviceMode deviceMode_ = NONE;

// Flag indicating that deviceMode has changed
bool deviceModeChanged_ = false;

// MOD_IN true if bluetooth mode
static volatile int8_t MOD_IN_ = 0x01; //start in WiFi mode after programming

// Content in audio buffer (provided by esp32-audioI2S library)
uint32_t audioBufferFilled_ = 0;

// Size of audio buffer (provided by esp32-audioI2S library)
uint32_t audioBufferSize_ = 0;

// Current station index
uint8_t stationIndex_ = 0;

// Flag to indicate the user wants to changed the station
bool stationChanged_ = true;

// Flag to indicate that audio is muted after tuning to a new station
bool stationChangedMute_ = true;

// Name of the current station as provided by the stream header data
String stationStr_ = "";

// Flag indicating the station name has changed
bool stationUpdatedFlag_ = false;

// Flag indicating that the connection to a host could not be established
bool connectionError_ = false;

// Info about current song as provided by the stream meta data or from AVRC data
String infoStr_ = "";

// Song artist provided by AVRC data (bluetooth)
String artistStr_ = "";

// Song title provided by AVRC data (bluetooth)
String titleStr_ = "";

// Flag indicating the song title has changed
bool infoUpdatedFlag_ = false;

// Position of the song title sprite on the screen (used for scrolling)
int16_t titlePosX_ = SCREEN_WIDTH;

// Audio volume to be set by the audio task
int16_t volumeCurrent_ = 0;

// Volume as float value for fading
float_t volumeCurrentF_ = 0.0f;

// Flag indicating the volume needs to be set by the audio task
bool volumeCurrentChangedFlag_ = true;

// Playstate of the audio stream
bool isPlaying_ = false;

// Audio volume that is set during normal operation
uint8_t volumeNormal_ = 20;

// Time in milliseconds at which the connection to the chosen stream has been established
uint64_t timeConnect_ = 0;

int16_t titleTextWidth_ = 0;

uint16_t holdCounter_ = 0;
int8_t volumeChange_ = 0;

int8_t batteryLevel_ = 0;

bool display_present = false;

// Forward declaration of the volume change callback in bluetooth sink mode
void avrc_volume_change_callback(int vol);

// Forward declaration of the connection state change callback in bluetooth sink mode
void a2dp_connection_state_changed(esp_a2d_connection_state_t state, void*);

// Forward declaration of the metadata callback in bluetooth sink mode
void avrc_metadata_callback(uint8_t id, const uint8_t *text);

/*
* Timer0, used for blinking the LED and counting seconds from power on.
*/
bool IRAM_ATTR Timer0_ISR(void * timerNo){
  /*Blink */
  static bool ledToggle = 0;
  digitalWrite(PIN_LED,ledToggle);
  ledToggle=!ledToggle;
  /*Tick*/
  tick++;
  return true;
}

//inverval for charging and battery level
unsigned long previousMillisLoop = 0;
const long intervalLoop = 1000;

//nRFLink receive variables
String url_ = "";
String urlPlaceholder_ = "";
bool isReadingUrl_ = false;

#define MAX_URL_LENGTH 141 // Define the maximum length of the URL

//Struct for receiving data from nRF
struct nrfReceivePayload_t {
    char url[MAX_URL_LENGTH];
    bool isPlaying;
    int8_t volume;
    uint8_t paramBitMask; // 0b00000000 <- 00 unused 0/1 url 0/1 isPlaying 0/1 volume 0/1 deviceModeChanged 00/01/10/11 deviceMode
};

//Struct for transmitting data to nRF
struct nrfTransmitPayload_t {
    bool isPlaying;
    DeviceMode deviceMode;
    int8_t volume;
    int8_t batteryLevel;
};

// Struct for holding the previous state
struct PrevState {
    t_DeviceMode deviceMode;
    bool playState;
    int volume;
    int batteryLevel;
};

// Initialize the previous state
PrevState prevState = {BOOT, false, -1, -1};

//Timer 3 ISR used for handling the power button and changing the device mode, contains the state machine for the device
bool IRAM_ATTR Timer3_ISR(void * timerNo){
    /*Power logic*/ 
    bool BTN_IN = analogRead(PIN_BTN) >= SW_THRESHOLD;
    if (BTN_IN) {
        holdCounter_++;
    }
    
    switch (deviceMode_) {
    case WIFI:
        if (!BTN_IN && holdCounter_ >= BTN_SINGLE_PRESS) {
            deviceMode_ = BT;
            MOD_IN_ = (deviceMode_ & 0x03) | ((deviceMode_ == BT ? 1 : 0) << 2);
            holdCounter_ = 0;
            deviceModeChanged_ = true;
        } else if (!BTN_IN && holdCounter_ > 1 && holdCounter_ < BTN_SINGLE_PRESS) {
            //Save current mode in the third bit of MOD_IN_
            DeviceMode temp = deviceMode_;
            if (digitalRead(PIN_CHG)) {
                temp = NONE;
            } else {
                temp = CHG;
            }
            MOD_IN_ = (temp & 0x03) | ((deviceMode_ == BT ? 1 : 0) << 2);
            deviceMode_ = temp;
            holdCounter_ = 0;
            deviceModeChanged_ = true;
        }
        break;
    case BT:
        if (!BTN_IN && holdCounter_ >= BTN_SINGLE_PRESS) {
            deviceMode_ = WIFI;
            MOD_IN_ = (deviceMode_ & 0x03) | ((deviceMode_ == BT ? 1 : 0) << 2);
            holdCounter_ = 0;
            deviceModeChanged_ = true;
        } else if (!BTN_IN && holdCounter_ > 1 && holdCounter_ < BTN_SINGLE_PRESS) {
            //Save current mode in the third bit of MOD_IN_
            DeviceMode temp = deviceMode_;
            if (digitalRead(PIN_CHG)) {
                temp = NONE;
            } else {
                temp = CHG;
            }
            MOD_IN_ = (temp & 0x03) | ((deviceMode_ == BT ? 1 : 0) << 2);
            deviceMode_ = temp;
            holdCounter_ = 0;
            deviceModeChanged_ = true;
        }
        break;
    case CHG:
        if (!BTN_IN && holdCounter_ > 1 && holdCounter_ < BTN_SINGLE_PRESS) {
            deviceMode_ = static_cast<t_DeviceMode>((MOD_IN_ >> 2) & 0x03);
            holdCounter_ = 0;
            deviceModeChanged_ = true;
        }
        if (holdCounter_ > BTN_SINGLE_PRESS) {
          holdCounter_ = 0;
        }
        if (digitalRead(PIN_CHG)) {
            digitalWrite(PIN_PSU_EN,HIGH);
            deviceMode_ = NONE;
            MOD_IN_ = (deviceMode_ & 0x07); 
            holdCounter_ = 0;
            deviceModeChanged_ = true;
        }
        digitalWrite(PIN_PSU_EN,HIGH);
        break;
    case NONE:
        if (holdCounter_ > BTN_LONG_PRESS && BTN_IN) {
          digitalWrite(PIN_PSU_EN,LOW);
        } else {
        digitalWrite(PIN_PSU_EN,HIGH);
        }
        if (!BTN_IN && holdCounter_ > 1 && holdCounter_ < BTN_SINGLE_PRESS) {
            deviceMode_ = static_cast<t_DeviceMode>((MOD_IN_ >> 2) & 0x03);
            holdCounter_ = 0;
            deviceModeChanged_ = true;
        }
        
        if (!BTN_IN && holdCounter_ < BTN_LONG_PRESS) {
          holdCounter_ = 0;
        }
        if (!digitalRead(PIN_CHG)) {
            deviceMode_ = CHG;
            MOD_IN_ = (deviceMode_ & 0x07); 
            holdCounter_ = 0;
            deviceModeChanged_ = true;
        }
        break;
    default:
        break;
    }
    return true;
}


//Encoder interrupts for the A pin, used to detect the direction of rotation
void IRAM_ATTR encA_ISR(){ //~7us
  detachInterrupt(digitalPinToInterrupt(PIN_ENC_A));
  encB = digitalRead(PIN_ENC_B);
  if(encB){
    attachInterrupt(digitalPinToInterrupt(PIN_ENC_B), encB_ISR, FALLING);
  }
  else{
    attachInterrupt(digitalPinToInterrupt(PIN_ENC_B), encB_ISR, RISING);
  }
  if(encA != encB){
    ENC_COUNT+=ENC_VEL;
    volumeChange_++;
  }
}

//Encoder interrupts for the B pin, used to detect the direction of rotation
void IRAM_ATTR encB_ISR(){ //~7us
  detachInterrupt(digitalPinToInterrupt(PIN_ENC_B));
  encA = digitalRead(PIN_ENC_A);
  if(encA){
    attachInterrupt(digitalPinToInterrupt(PIN_ENC_A), encA_ISR, FALLING);
  }
  else{
    attachInterrupt(digitalPinToInterrupt(PIN_ENC_A), encA_ISR, RISING);
  }
  if(encA != encB){
    ENC_COUNT-=ENC_VEL;
    volumeChange_--;
  }
}



/**
 * Shows a welcome message at startup of the device on the OLED display.
 */
void showWelcomeMessage() {
    // Show some information on the startup screen
    if (display_present) {
        display.clearDisplay();
        display.setTextSize(1);
        display.setTextColor(SH110X_WHITE,0);
        display.setCursor(0,25);
        display.print(deviceName);
        display.display();
    }
}

/**
 * Displays the volume on the OLED screen.
 * 
 * @param volume Volume to be displayed on the OLED screen.
 */
void showVolume(uint8_t volume) {
    if (display_present) {
        display.setTextSize(1);
        display.setTextColor(SH110X_WHITE,0);
        display.setCursor(0,0);
        display.print("Volume: ");
        display.printf("%3d", volume);
        display.display();
    }
}

/**
 * Displays the battery level on the OLED screen.
 */
void showBattery() {
    if (display_present) {
        display.setCursor(65,55);
        display.print("Batt: ");
        display.printf("%3d", batteryLevel_);
        display.print("%");
        display.display();
    }
}
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
void loop() {     
    //If device mode changed flag, change the device mode
    if (deviceModeChanged_) {
        nrfTransmit();
        changeDeviceMode();
        deviceModeChanged_ = false;
    } else {
      unsigned long currentMillisLoop = millis();
      nrfCheck(); // Check for incoming messages from the nRFLink
      readEncState(); // Read the encoder state
      
      //Update and show battery level and transmit the current state to the nRFLink every intervalLoop milliseconds
      if (deviceMode_ == WIFI || deviceMode_ == BT) {
        if (currentMillisLoop - previousMillisLoop >= intervalLoop) {
            previousMillisLoop = currentMillisLoop;
            processBatteryLevel();
            showBattery();
            nrfTransmit();
        }
      }

      if (deviceMode_ == WIFI) {
          if (volumeCurrentChangedFlag_) {
            showVolume(volumeCurrent_); // Show the updated volume on the OLED screen
          }
          if (connectionError_) {
              showVolume(volumeCurrent_);
              display.setCursor(0,30);
              display.println("Stream unavailable"); // Show error message on the OLED screen
              digitalWrite(PIN_AMP_EN,LOW); //Turn off amplifier
              vTaskDelay(200 / portTICK_PERIOD_MS); // Wait until next cycle
          }
          else {
              // Update the station name if flag is raised
              if (stationUpdatedFlag_ && !stationChanged_) {
                  volumeNormal_ = volumeCurrent_;
                  volumeCurrent_ = 0;
                  volumeCurrentChangedFlag_ = true;
                  showVolume(volumeCurrent_);
                  showStation();
                  stationUpdatedFlag_ = false; // Clear update flag  
                  digitalWrite(PIN_AMP_EN,HIGH); //Enable amplifier
                  while (volumeCurrent_ < volumeNormal_){
                    volumeCurrentF_ += 0.25;
                    volumeCurrent_ = (uint8_t) volumeCurrentF_;
                    volumeCurrentChangedFlag_ = true;
                    showVolume(volumeCurrent_);
                  }
              }
              showSongInfo(); // Show the song information on the OLED screen
              vTaskDelay(20 / portTICK_PERIOD_MS); // Wait until next cycle
          }
      } else if (deviceMode_ == BT) {
              // Update the station name if flag is raised
              if (stationUpdatedFlag_) {
                  showStation();
                  stationUpdatedFlag_ = false; // Clear update flag
              }

              showSongInfo(); // Show the song information on the OLED screen

              if (volumeCurrentChangedFlag_) {
                  showVolume(volumeCurrent_); // Show the updated volume on the OLED screen
              } 
              
              showPlayState(a2dp_.get_audio_state() == ESP_A2D_AUDIO_STATE_STARTED); // Show the play state on the OLED screen
              vTaskDelay(20 / portTICK_PERIOD_MS); // Wait until next cycle
      } else if (deviceMode_ == CHG) {
        if (currentMillisLoop - previousMillisLoop >= intervalLoop) {
            previousMillisLoop = currentMillisLoop;
            //Update and show battery level and transmit the current state to the nRFLink every intervalLoop milliseconds
            processBatteryLevel();
            showBattery();
            nrfTransmit();
            //Use the RGB LED to show 5 different battery levels (0-20, 20-40, 40-60, 60-80, 80-100), added the 20 and 60 levels to control the toggling of the LEDs
            if (batteryLevel_ < 20) {
                digitalWrite(PIN_LED_R, !digitalRead(PIN_LED_R)); // Toggle red LED
                digitalWrite(PIN_LED_G, HIGH);  // Make sure green LED is off
                digitalWrite(PIN_LED_B, HIGH);  // Make sure blue LED is off
            } else if (batteryLevel_ == 20) {
                digitalWrite(PIN_LED_R, LOW); // Turn on red LED
                digitalWrite(PIN_LED_G, HIGH);  // Make sure green LED is off
                digitalWrite(PIN_LED_B, HIGH);  // Make sure blue LED is off
            } else if (batteryLevel_ > 20 && batteryLevel_ < 40) {
                digitalWrite(PIN_LED_R, !digitalRead(PIN_LED_R)); // Toggle red LED
                digitalWrite(PIN_LED_G, !digitalRead(PIN_LED_G)); // Toggle green LED
                digitalWrite(PIN_LED_B, HIGH);  // Make sure blue LED is off
            } else if (batteryLevel_ >= 40 && batteryLevel_ <= 60) {
                digitalWrite(PIN_LED_B, !digitalRead(PIN_LED_B)); // Toggle blue LED
                digitalWrite(PIN_LED_R, HIGH);  // Make sure red LED is off
                digitalWrite(PIN_LED_G, HIGH);  // Make sure green LED is off
            } else if (batteryLevel_ == 60) {
                digitalWrite(PIN_LED_B, LOW); // Toggle red LED
                digitalWrite(PIN_LED_G, HIGH); // Toggle green LED
                digitalWrite(PIN_LED_B, HIGH);  // Make sure blue LED is off
            } else if (batteryLevel_ > 60 && batteryLevel_ <= 80) {
                digitalWrite(PIN_LED_B, !digitalRead(PIN_LED_B)); // Toggle blue LED
                digitalWrite(PIN_LED_R, HIGH);  // Make sure red LED is off
                digitalWrite(PIN_LED_G, !digitalRead(PIN_LED_G));  // Make sure green LED is off
            } else if (batteryLevel_ > 80) {
                digitalWrite(PIN_LED_G, !digitalRead(PIN_LED_G)); // Toggle green LED
                digitalWrite(PIN_LED_R, HIGH);  // Make sure red LED is off
                digitalWrite(PIN_LED_B, HIGH);  // Make sure blue LED is off
            }

        }
      } else if (deviceMode_ == NONE) {
        // Neither WIFI, BT or CHG
        if (currentMillisLoop - previousMillisLoop >= intervalLoop) {
          previousMillisLoop = currentMillisLoop;
          processBatteryLevel();
          showBattery();
          nrfTransmit();
        }
      }
      
    }
}



/*
* metadata callback for the bluetooth audio library
*/
void avrc_metadata_callback(uint8_t id, const uint8_t *text) { 
    switch (id) {
        case ESP_AVRC_MD_ATTR_TITLE:
            titleStr_ = (char*) text;
            break;
        
        case ESP_AVRC_MD_ATTR_ARTIST:
            artistStr_ = (char*) text;
            break;
    }    

    if ( artistStr_.isEmpty() ) {
        infoStr_ = titleStr_;
    }
    else {
        if ( titleStr_.isEmpty() ) {
            infoStr_ = artistStr_;
        }
        else {
            infoStr_ = artistStr_ + " - " + titleStr_;
        }
    }
    
    infoUpdatedFlag_ = true; // Raise flag for the display update routine
}

/*
* connection state callback for the bluetooth audio library
*/
void a2dp_connection_state_changed(esp_a2d_connection_state_t state, void*) {

    if (state != ESP_A2D_CONNECTION_STATE_CONNECTED) {
        infoStr_ = "not connected";
        infoUpdatedFlag_ = true; // Raise flag for the display update routine
    }
}

/*
* volume change callback
*/
void avrc_volume_change_callback(int vol) {
    volumeCurrent_ = vol;
    volumeCurrentChangedFlag_ = true;
}

//mainly optional callbacks for the audio library, left in for future use or debugging
//Mainly from the 'M5StickC_WebRadio' project by Ernst Sikora.
/* 
void audio_info(const char *info){ 
}
void audio_id3data(const char *info){  //id3 metadata 
}
void audio_eof_mp3(const char *info){  //end of file 

}
void audio_showstation(const char *info){ 
    stationStr_ = info;
    stationUpdatedFlag_ = true; // Raise flag for the display update routine

    #ifdef DEBUG
        Serial.print("station     ");
        Serial.println(info);
    #endif
}
void audio_showstreamtitle(const char *info){ 
    if (deviceMode_ == WIFI) {
        infoStr_ = info;
    }
    else {
        std::string title(metadata.title);
        std::string artist(metadata.artist);
        infoStr_ = (title + " - " + artist).c_str();
        //infoStr_ = metadata.title + " - " + metadata.artist;
    }
    infoUpdatedFlag_ = true; // Raise flag for the display update routine


}
void audio_bitrate(const char *info){ 
}
void audio_commercial(const char *info){  //duration in sec //audio_commercial
}
void audio_icyurl(const char *info){  //homepage 
}

void audio_lasthost(const char *info){  //stream URL played 
}

void audio_eof_speech(const char *info){ 
}
 */

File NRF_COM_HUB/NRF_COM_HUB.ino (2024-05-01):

/*
  Rui Santos
  Complete project details at Complete project details at https://RandomNerdTutorials.com/esp32-http-get-post-arduino/

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
  The above copyright notice and this permission notice shall be included in all
  copies or substantial portions of the Software.
*/

#include <WiFi.h>
#include <HTTPClient.h>
#include <Arduino_JSON.h>
#include <RF24.h>
// #include <nRF24L01.h>
#include "WifiCredentials.h"
#include <RF24Network.h>

// NRF intialisation and variables
//#define MAX_PAYLOAD_SIZE   144 //Change this value to allow larger nrfNetwork payloads
RF24 radio(17,16); // (CE, CSN)
RF24Network network(radio);
int channel = 0x76;
const uint16_t this_node = 00;
const uint16_t other_node = 01;

//#define DEBUG

enum WiFiState {
  DISCONNECTED,
  DISCONNECTING,
  CONNECTING,
  CONNECTED
};

WiFiState wifiState = DISCONNECTED;
unsigned long wifiConnectStart;

enum DeviceMode {WIFI = 0, BT = 1, CHG = 2, NONE = 3};

typedef enum DeviceMode t_DeviceMode;

//Domain name with URL path or IP address with path
const char* ServerName = "https://internetradioapi.azurewebsites.net/radio/play";
// the following variables are unsigned longs because the time, measured in
// milliseconds, will quickly become a bigger number than can be stored in an int.
unsigned long lastTime = 0;
unsigned long lastPostTime = 2000; // Set to 2 seconds to allow the first reading to be published
// Timer set to 10 minutes (600000)
//unsigned long timerDelay = 600000;
// Set timer to 5 seconds (5000)
unsigned long timerDelay = 5000;

uint8_t retryCounter = 0;


// Initialsing variables for extracting and processing JSON data
String serverReadings;
String oldUrlString;
String oldIsPlayingString;
String oldVolumeString;
String urlString;
String isPlayingString;
String volumeString;
String oldDeviceModeString;
String deviceModeString;


const char* RadioURL;
const char* RadioIsPlaying;
const char* RadioVolume;
const char* RadioDeviceMode;

// Protoype functions
String httpGETRequest(const char* serverName);
void httpPostRequest(const char* serverName, String payload);
void connectToWiFi(void);
String nrfCheck();
String postDataString(bool isPlaying, DeviceMode deviceMode, int8_t volume, uint8_t batterylevel);

#define MAX_URL_LENGTH 141 // Define the maximum length of the URL

struct nrfTransmitPayload_t {  // Structure of our payload
  char url[MAX_URL_LENGTH];
  bool isPlaying;
  int8_t volume;
  uint8_t paramBitMask = 0;
};

struct nrfReceivePayload_t
{
  bool isPlaying;
  DeviceMode deviceMode;
  int8_t volume;
  uint8_t batterylevel;
};

void setup() {
  Serial.begin(115200);
  
  connectToWiFi();

  #ifdef DEBUG
    Serial.println("Timer set to 5 seconds (timerDelay variable), it will take 5 seconds before publishing the first reading.");
  #endif
  
  // Setting up nRF radio
  radio.begin();
  radio.setChannel(channel);
  network.begin(this_node);
}

void loop() {
  network.update();
  String postWebData = nrfCheck();
  // Check WiFi connection status and reconnect if necessary // MÅSKE RYK DET UD AF IF MILLIS()
  connectToWiFi();
  if (postWebData != "") {
    if (millis() - lastPostTime >= 5000) { // 5 seconds have passed since the last post
      // Send data to web server every 5 seconds
      if (WiFi.status() == WL_CONNECTED) {
        httpPostRequest(ServerName, postWebData);
        lastPostTime = millis();
        delay(1000); // Delay of 1 second to allow the server to process the data 
      } else {
        #ifdef DEBUG
          Serial.println("WiFi Disconnected");
        #endif
      }
    }
  }
  //Send an HTTP GET request every 5 seconds
  if ((millis() - lastTime) > timerDelay) {
    
    //Check WiFi connection status
    if (WiFi.status() == WL_CONNECTED) {
              
      // Getting data from web server
      serverReadings = httpGETRequest(ServerName);
      JSONVar serverReadingsJSON = JSON.parse(serverReadings);
  
      // Checking the format of the JSONVAR
      if (JSON.typeof(serverReadingsJSON) == "undefined" || JSON.stringify(serverReadingsJSON) == "{}") {
        #ifdef DEBUG
          Serial.println("Parsing input failed or received empty JSON object!");
        #endif
        return;
      }

      #ifdef DEBUG
        Serial.print("JSON object = ");
        Serial.println(serverReadingsJSON);
        Serial.println();
      #endif

      RadioURL = serverReadingsJSON[0]["url"];
      RadioIsPlaying = serverReadingsJSON[0]["isPlaying"];
      RadioVolume = serverReadingsJSON[0]["volume"];
      RadioDeviceMode = serverReadingsJSON[0]["deviceMode"];

      // Serial.println("Extracted data from JSON object");
      // Serial.println(RadioURL);
      // Serial.println(RadioIsPlaying);
      // Serial.println(RadioVolume);
      // Serial.println(RadioDeviceMode);

      urlString = String(RadioURL);
      isPlayingString =  String(RadioIsPlaying);
      volumeString = String(RadioVolume);
      deviceModeString = String(RadioDeviceMode);

      // Serial.print("RadioURL: ");
      // Serial.println(urlString);
      // Serial.print("RadioIsPlaying: ");
      // Serial.println(isPlayingString);
      // Serial.print("RadioVolume: ");
      // Serial.println(volumeString);
      // Serial.print("RadioDeviceMode: ");
      // Serial.println(deviceModeString);

      if (urlString != oldUrlString || isPlayingString != oldIsPlayingString || volumeString != oldVolumeString || deviceModeString != oldDeviceModeString) {
        uint8_t paramBitMask = 0; // Create a bitmask to keep track of which parameters have changed
        #ifdef DEBUG
          Serial.println("New info detected");
        #endif
        if (urlString != oldUrlString) {
            paramBitMask |= 1 << 0; // Set bit 0
            #ifdef DEBUG
              Serial.println("URL changed");
            #endif
        }
        if (isPlayingString != oldIsPlayingString) {
            paramBitMask |= 1 << 1; // Set bit 1
            #ifdef DEBUG
              Serial.println("IsPlaying changed");
            #endif
        }
        if (volumeString != oldVolumeString) {
            paramBitMask |= 1 << 2; // Set bit 2
            #ifdef DEBUG
              Serial.println("Volume changed");
            #endif
        }
        oldUrlString = urlString;
        oldIsPlayingString = isPlayingString;
        oldVolumeString = volumeString;
        oldDeviceModeString = deviceModeString;
        // Serial.print("RadioURL: ");
        // Serial.println(oldUrlString);
        // Serial.print("RadioIsPlaying: ");
        // Serial.println(oldIsPlayingString);
        // Serial.print("RadioVolume: ");
        // Serial.println(oldVolumeString);
        // Serial.print("RadioDeviceMode: ");
        // Serial.println(oldDeviceModeString);
        // Serial.print("ParamBitMask: ");
        // Serial.println(paramBitMask, BIN);

        char oldUrlChar[oldUrlString.length() + 1];
        oldUrlString.toCharArray(oldUrlChar, oldUrlString.length() + 1);
        oldUrlChar[oldUrlString.length()] = '\0';
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

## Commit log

2024-04-17 Ported encoder functionality, added volume control, started button control
2024-04-19 ESP32 HTTP GET code
    return url oldURLString and name oldNameString as strings
2024-04-24 Added post function wit h voltageread and process
2024-04-24 Working "state machine" prototype
2024-04-24 First implementation of State and Charge light
2024-04-24 Updated Charge LEDs
2024-04-25 PIN definitions for NRF
2024-04-25 Added battery on display, testing PSU latching
2024-04-27 Added markdown for flowcharts
2024-05-01 Minor improvements and updated flowchart
2024-05-05 Added communication flow and updated readme
